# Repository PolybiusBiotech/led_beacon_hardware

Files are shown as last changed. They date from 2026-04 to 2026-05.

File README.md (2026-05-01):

# LED Beacon 🚀
> Upgrading cheap LED beacons for professional DMX/Art-Net stage control.

Hardware Render <!-- Tip: Export a nice 3D render from KiCAD -->

## 🚀 Manufacturing Status
- [ ] **Design:** Completed
- [ ] **Prototyping:** In Progress
- [ ] **Production:** Pending

## 📋 Quick Specs
- **MCU:** ESP32-C3-WROOM-02
- **Power:** +12V ±30% @ 2A
- **Connectivity:** DMX512 via 5 pin XLRs and WiFi

## 📂 Project Structure
- `/hardware`: KiCAD project files (Version 9.0.7).
- `/firmware`: PlatformIO project (Arduino/ESP-IDF framework).
- `/mechanical`: 3D-printable housing (.STEP).
- `/docs`: Specification, schematics and design calculations.
<!-- test: for test scripts -->

## 🛠 Setup & Development

### Hardware
- **Library Dependencies:** All footprints/symbols are [local to the repo / use standard KiCAD libs].
- **CI/CD:** Schematics are automatically exported to `/docs` on every push.

### Firmware
1. Open the `/firmware` folder in **VS Code**.
2. Ensure the **PlatformIO** extension is installed.
3. Connect your hardware via USB C port and click **Upload**.

## User Guide

1. Apply power via DC connector, 12V ±30% from a 3A capable supply.
2. Attach to DMX chain with 2x XLR 5pin cables
   * If at the end of the bus use a terminator plug
3. Select a DMX address with the DIP switch
   * This light consumes 20 slots so avoid address above 492.
   * Ensure that this light is >20 slots away from the next lights.
4. Disable the WiFi AP with the DIP switch unless needed for diagnostics
5. Use your DMX controller to send packets on the DMX chain.
   * Slots 1 to 10 control the brightness per channel
     * `0x00` is off
     * `0xFF` is on
   * Slots 11 to 20 control the strobe effect per channel
     * `0x00` is fully on
     * `0x01` strobes at 0.2Hz
     * `0xFF` strobes at 20Hz
6. Enjoy!

---
*Commissioned for Null Sector for EMF Camp 2026.*

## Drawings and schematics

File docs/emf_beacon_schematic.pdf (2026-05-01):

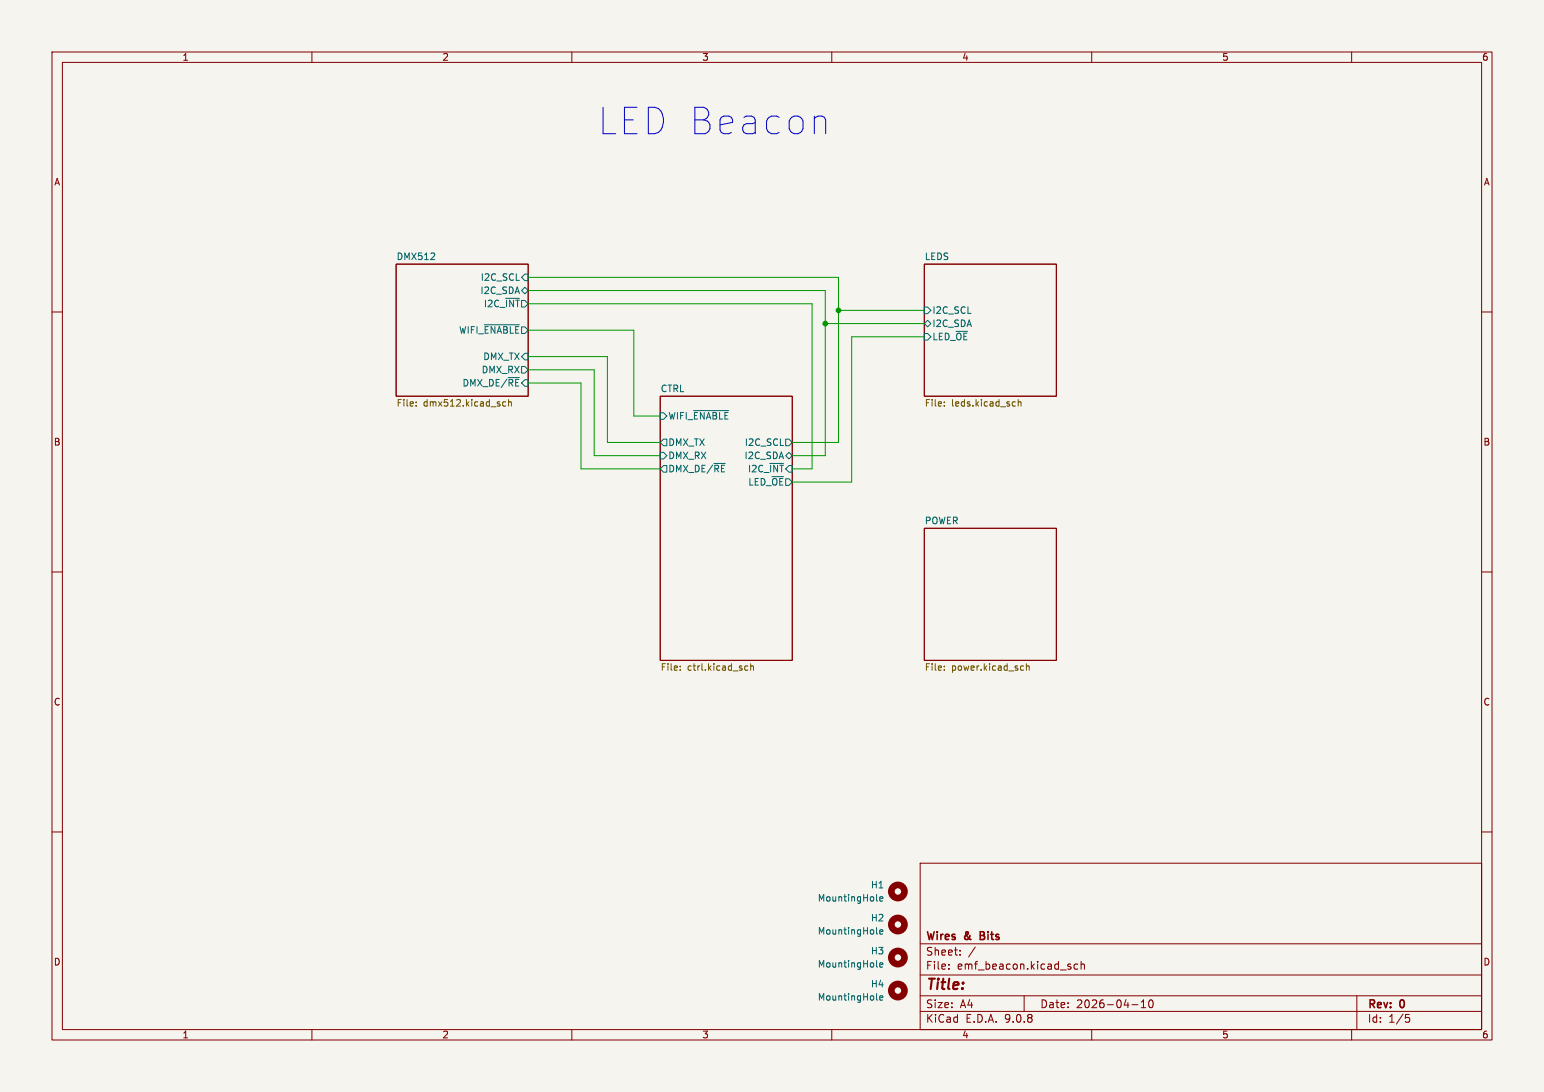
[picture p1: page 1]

WIFI_~{ENABLE} CTRL File: ctrl.kicad_sch DMX_DE/~{RE} DMX_RX DMX_TX

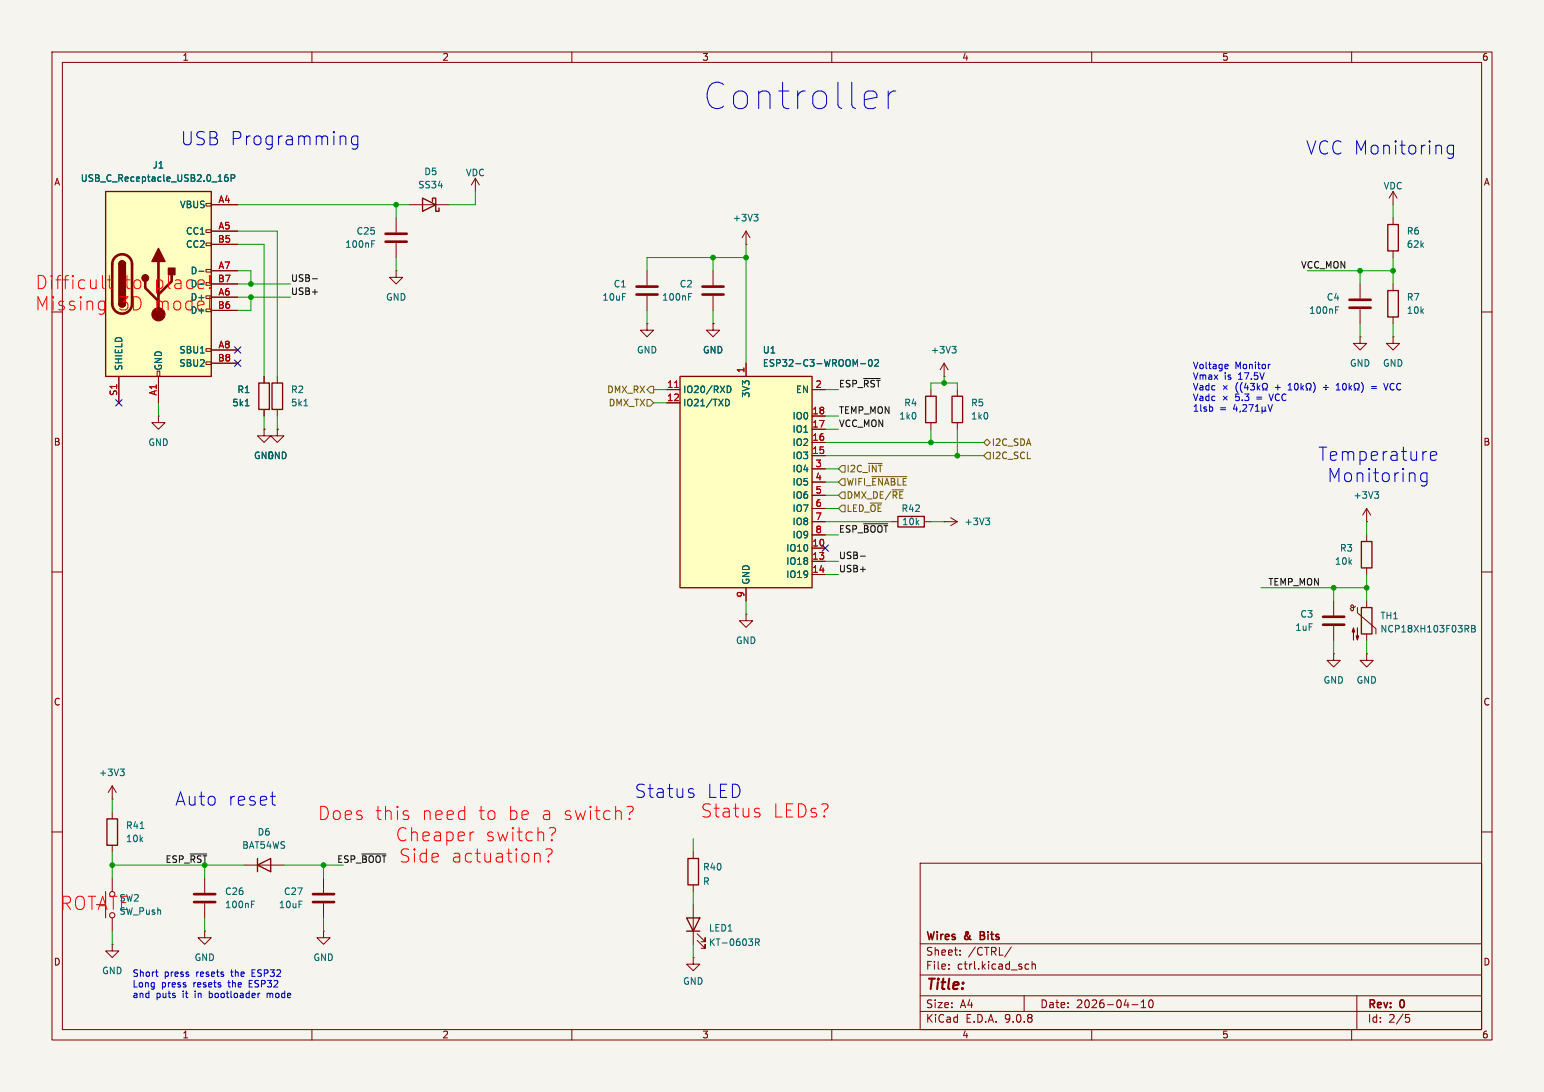
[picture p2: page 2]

Voltage Monitor Vmax is 17.5V

Vadc þÿ×þÿ((43k©+ þÿ10k©) þÿ÷þÿ10k©) = VCC
Vadc þÿ×5.3 = VCC
1lsb = þÿ4,271¼V

ESP_~{BOOT} USB+ Does this need to be a switch?

Short press resets the ESP32
Long press resets the ESP32

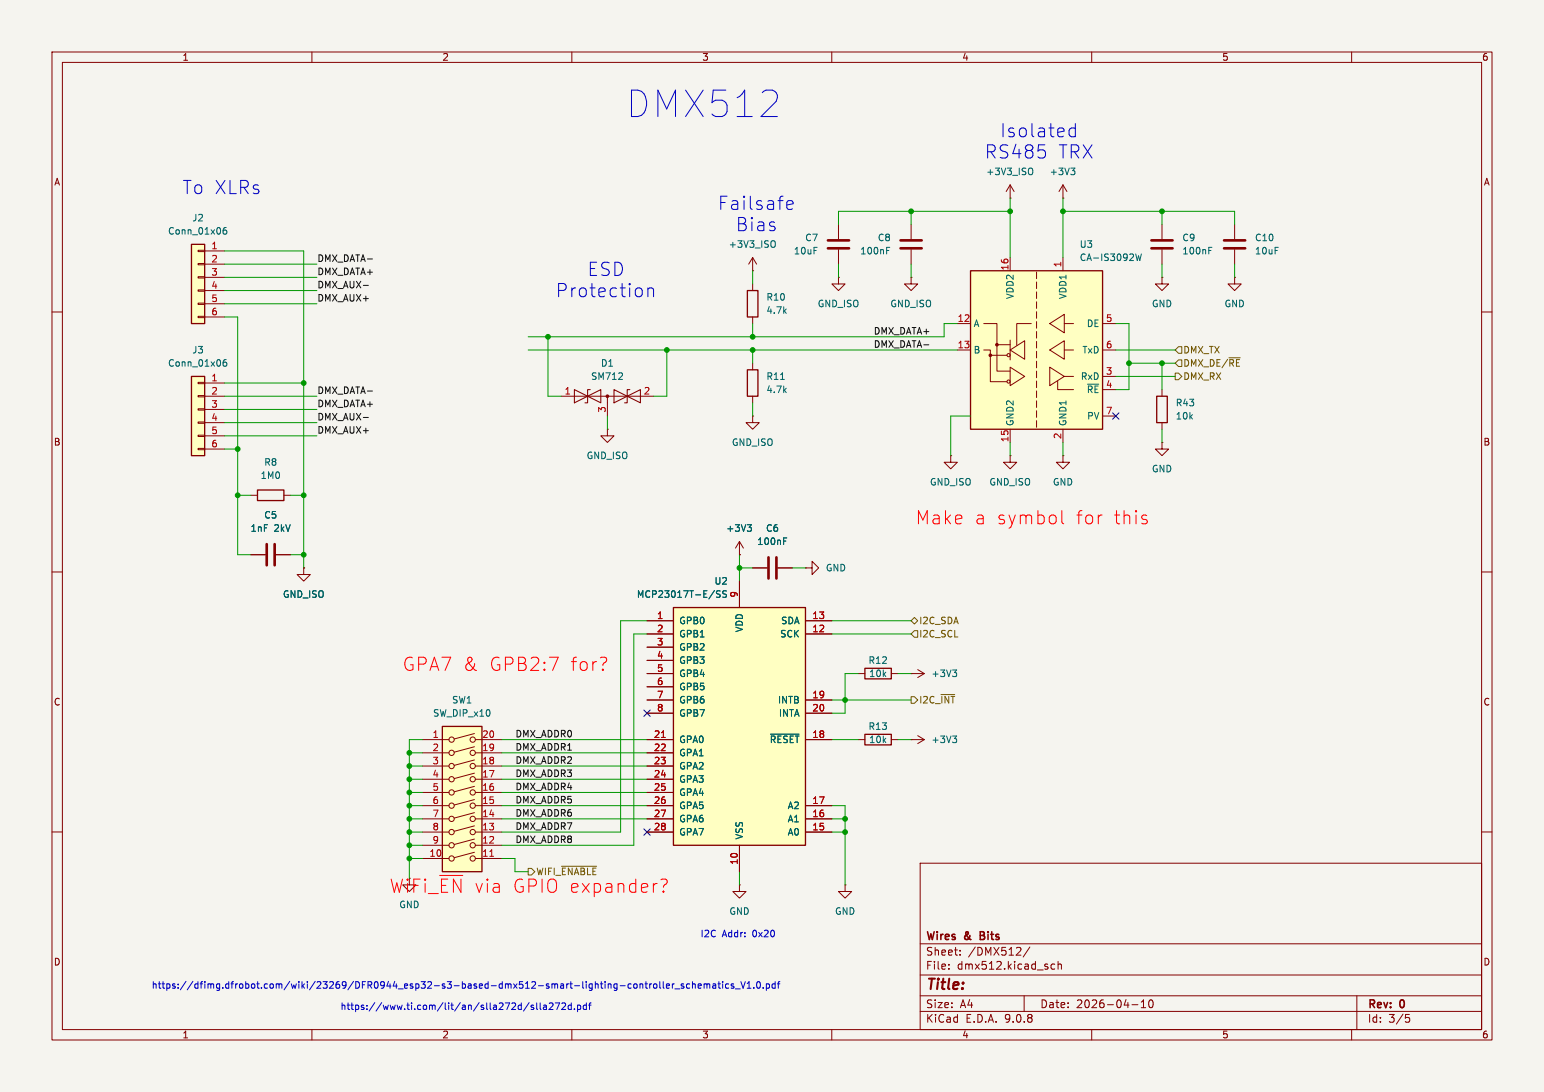
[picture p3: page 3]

9 VSS 10 GPB0 1 GPB1 2 GPB2 3 GPB3 4 GPB4 5 GPB5 6 GPB6 7 GPB7 8 GPA0 21 GPA1 22 GPA2 23 GPA3 24 GPA4 25 GPA5 26 GPA6 27 GPA7 28 U2 MCP23017T-E/SS GND GND GND GND_ISO

https://dfimg.dfrobot.com/wiki/23269/DFR0944_esp32-s3-based-dmx512-smart-lighting-controller_schematics_V1.0.pdf

https://www.ti.com/lit/an/slla272d/slla272d.pdf

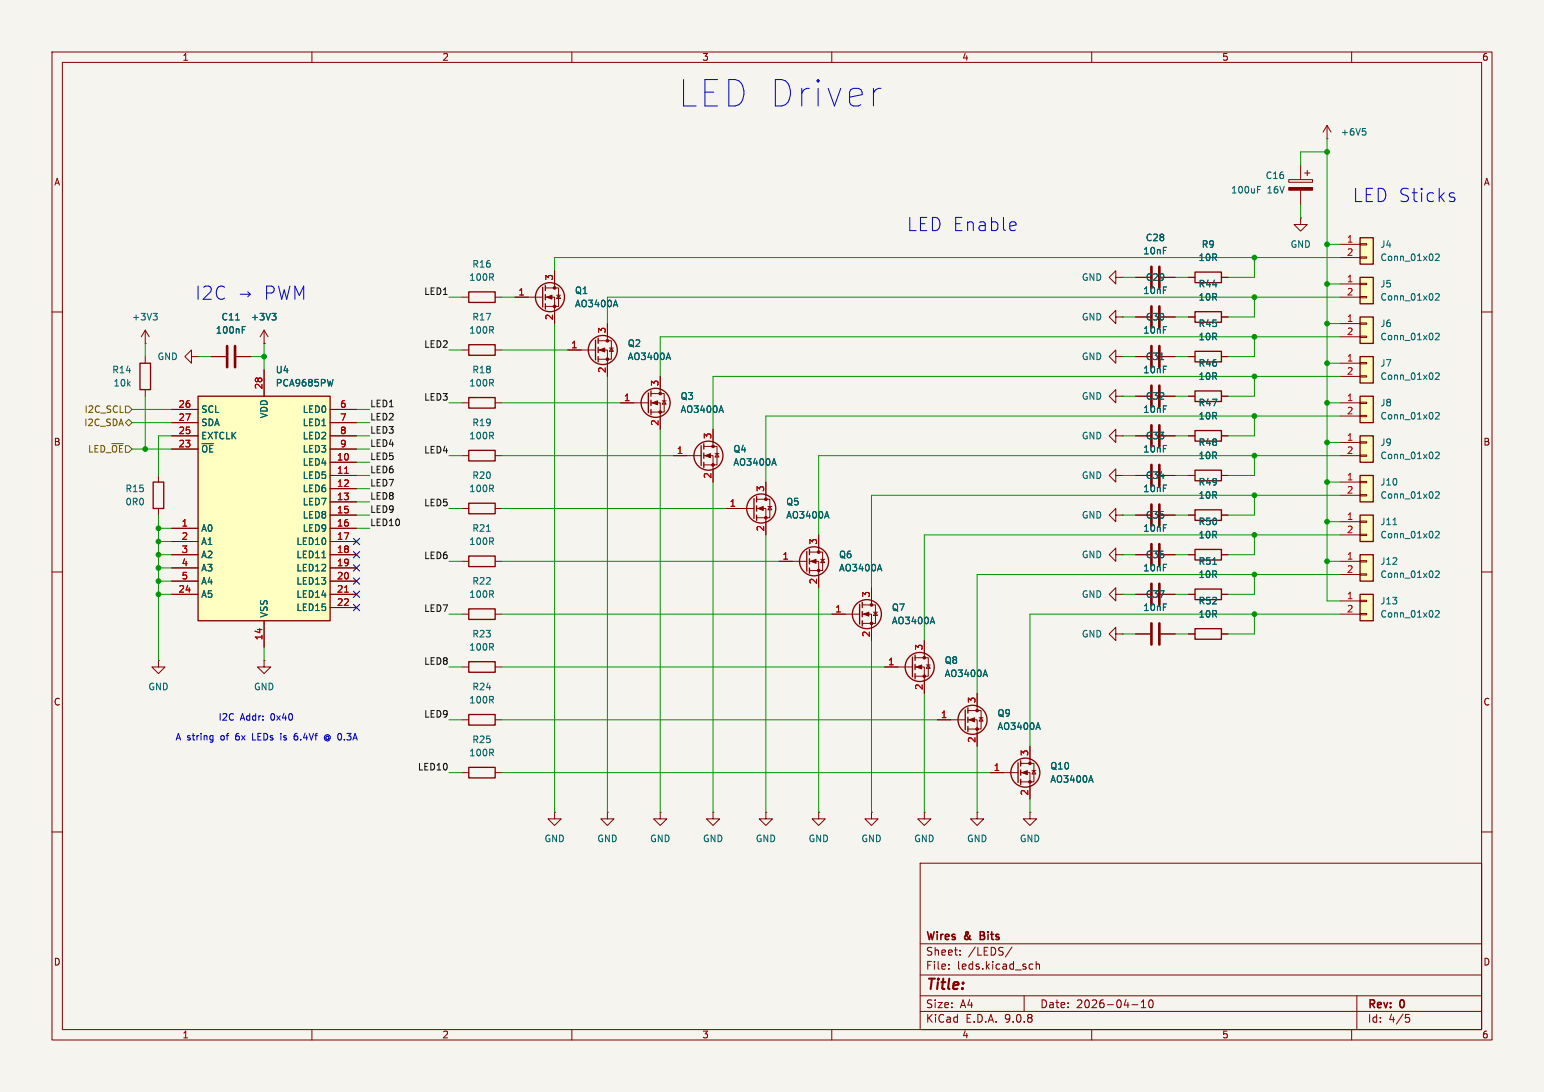
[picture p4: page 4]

3 2 Q10 AO3400A GND GND GND GND GND GND GND

A string of 6x LEDs is 6.4Vf @ 0.3A

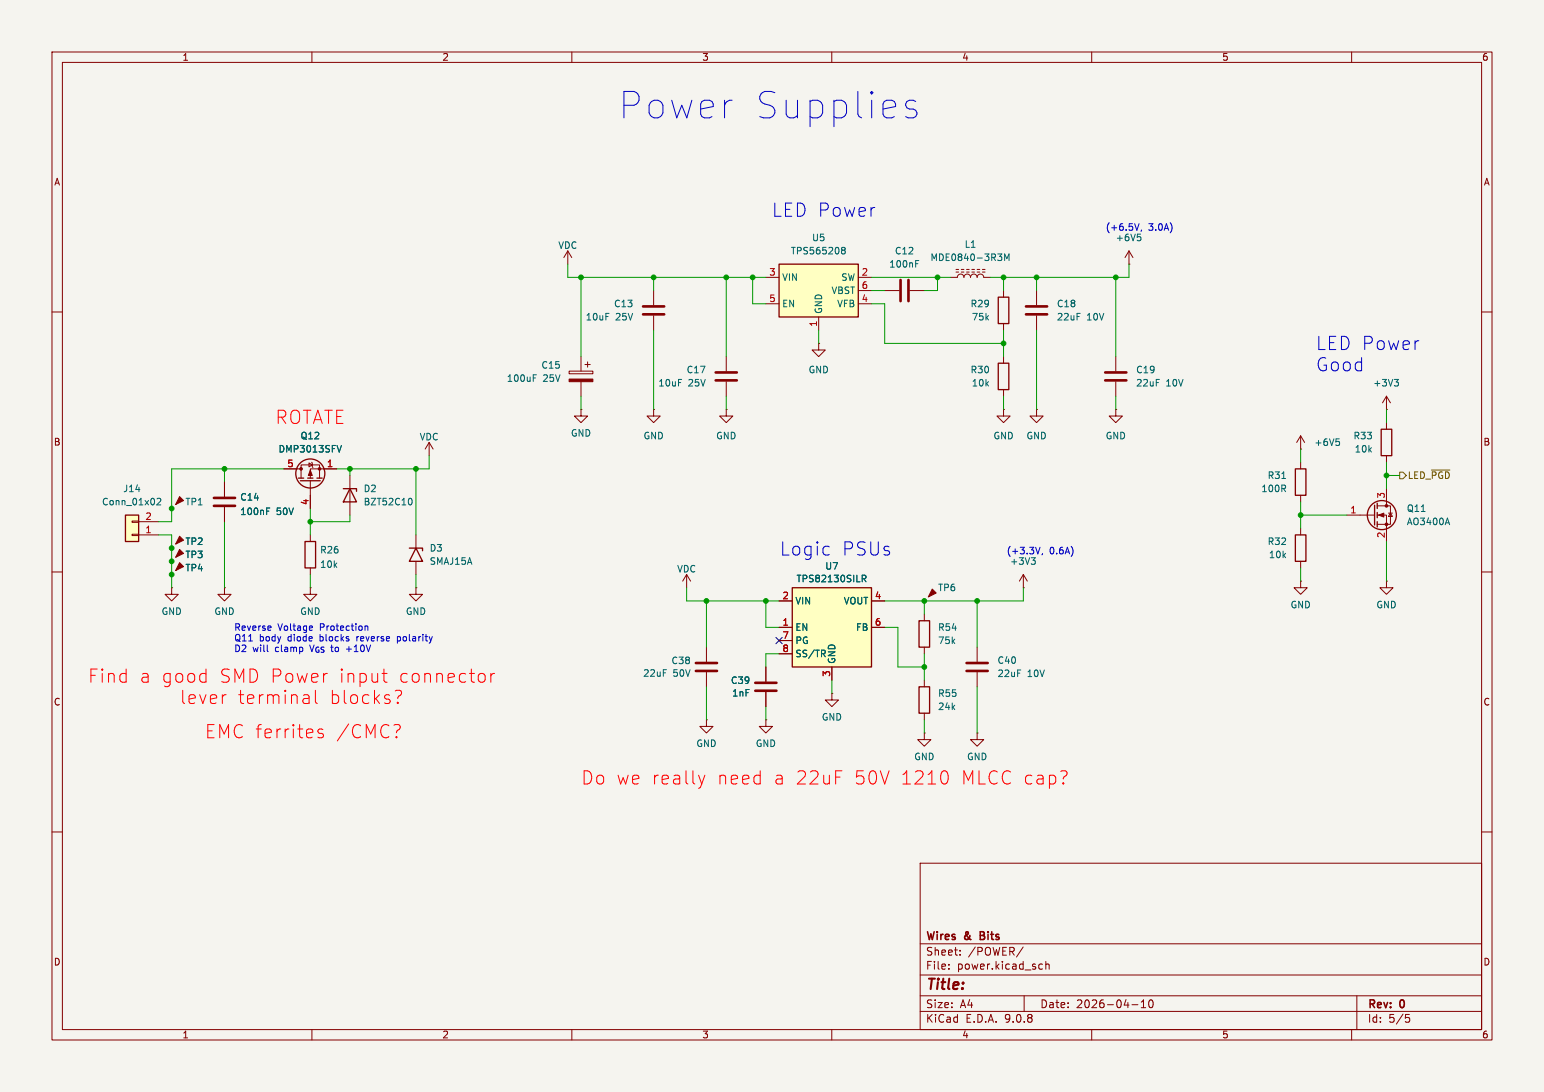
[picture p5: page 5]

Find a good SMD Power input connector

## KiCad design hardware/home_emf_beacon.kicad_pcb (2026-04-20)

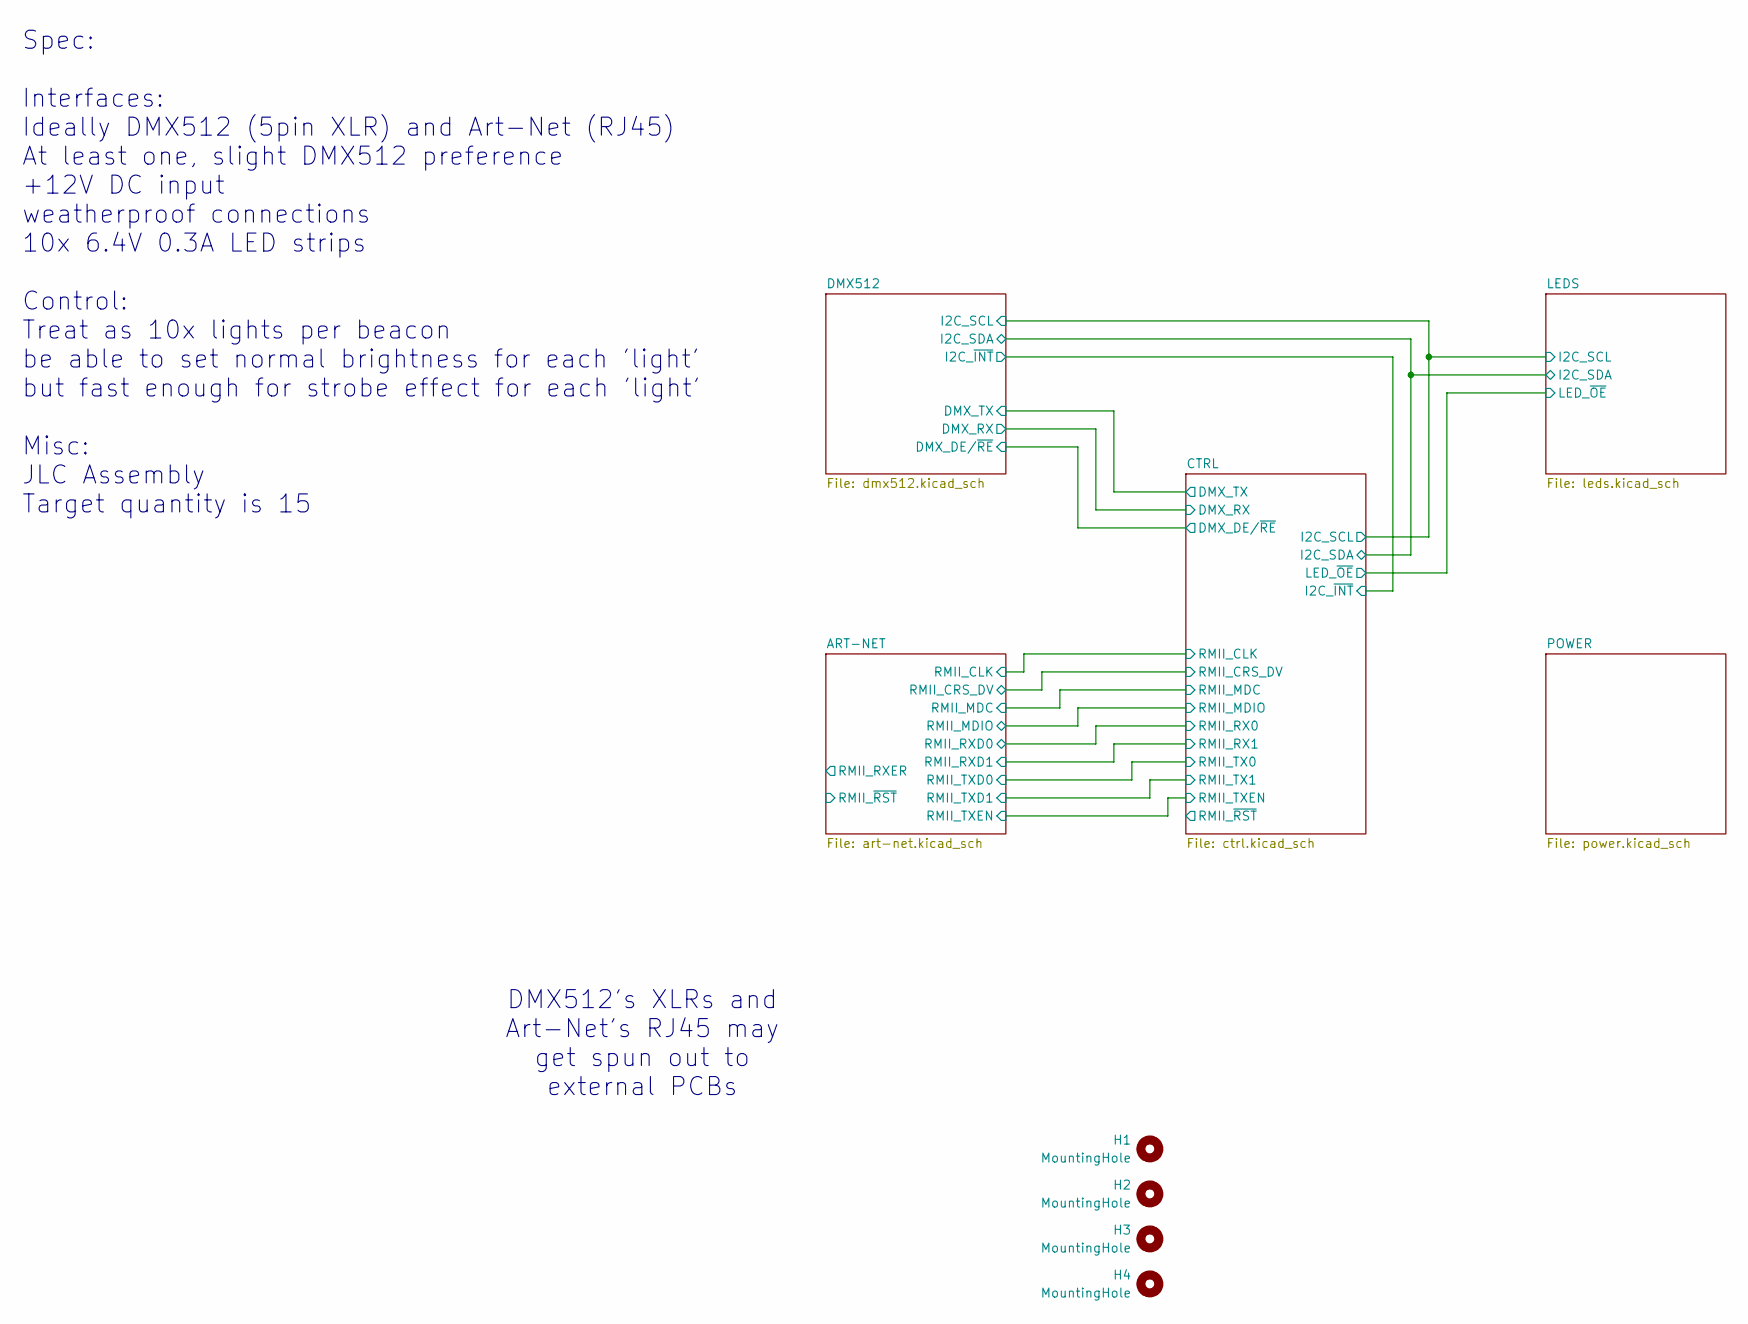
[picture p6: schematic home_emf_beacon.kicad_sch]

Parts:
H1, H2, H3, H4: MountingHole; MountingHole_4.3mm_M4

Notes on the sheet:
Spec: Interfaces: Ideally DMX512 (5pin XLR) and Art-Net (RJ45) At least one, slight DMX512 preference +12V DC input weatherproof connections 10x 6.4V 0.3A LED strips Control: Treat as 10x lights per beacon be able to set normal brightness for each 'light' but fast enough for strobe effect for each 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
DMX512's XLRs and Art-Net's RJ45 may get spun out to external PCBs

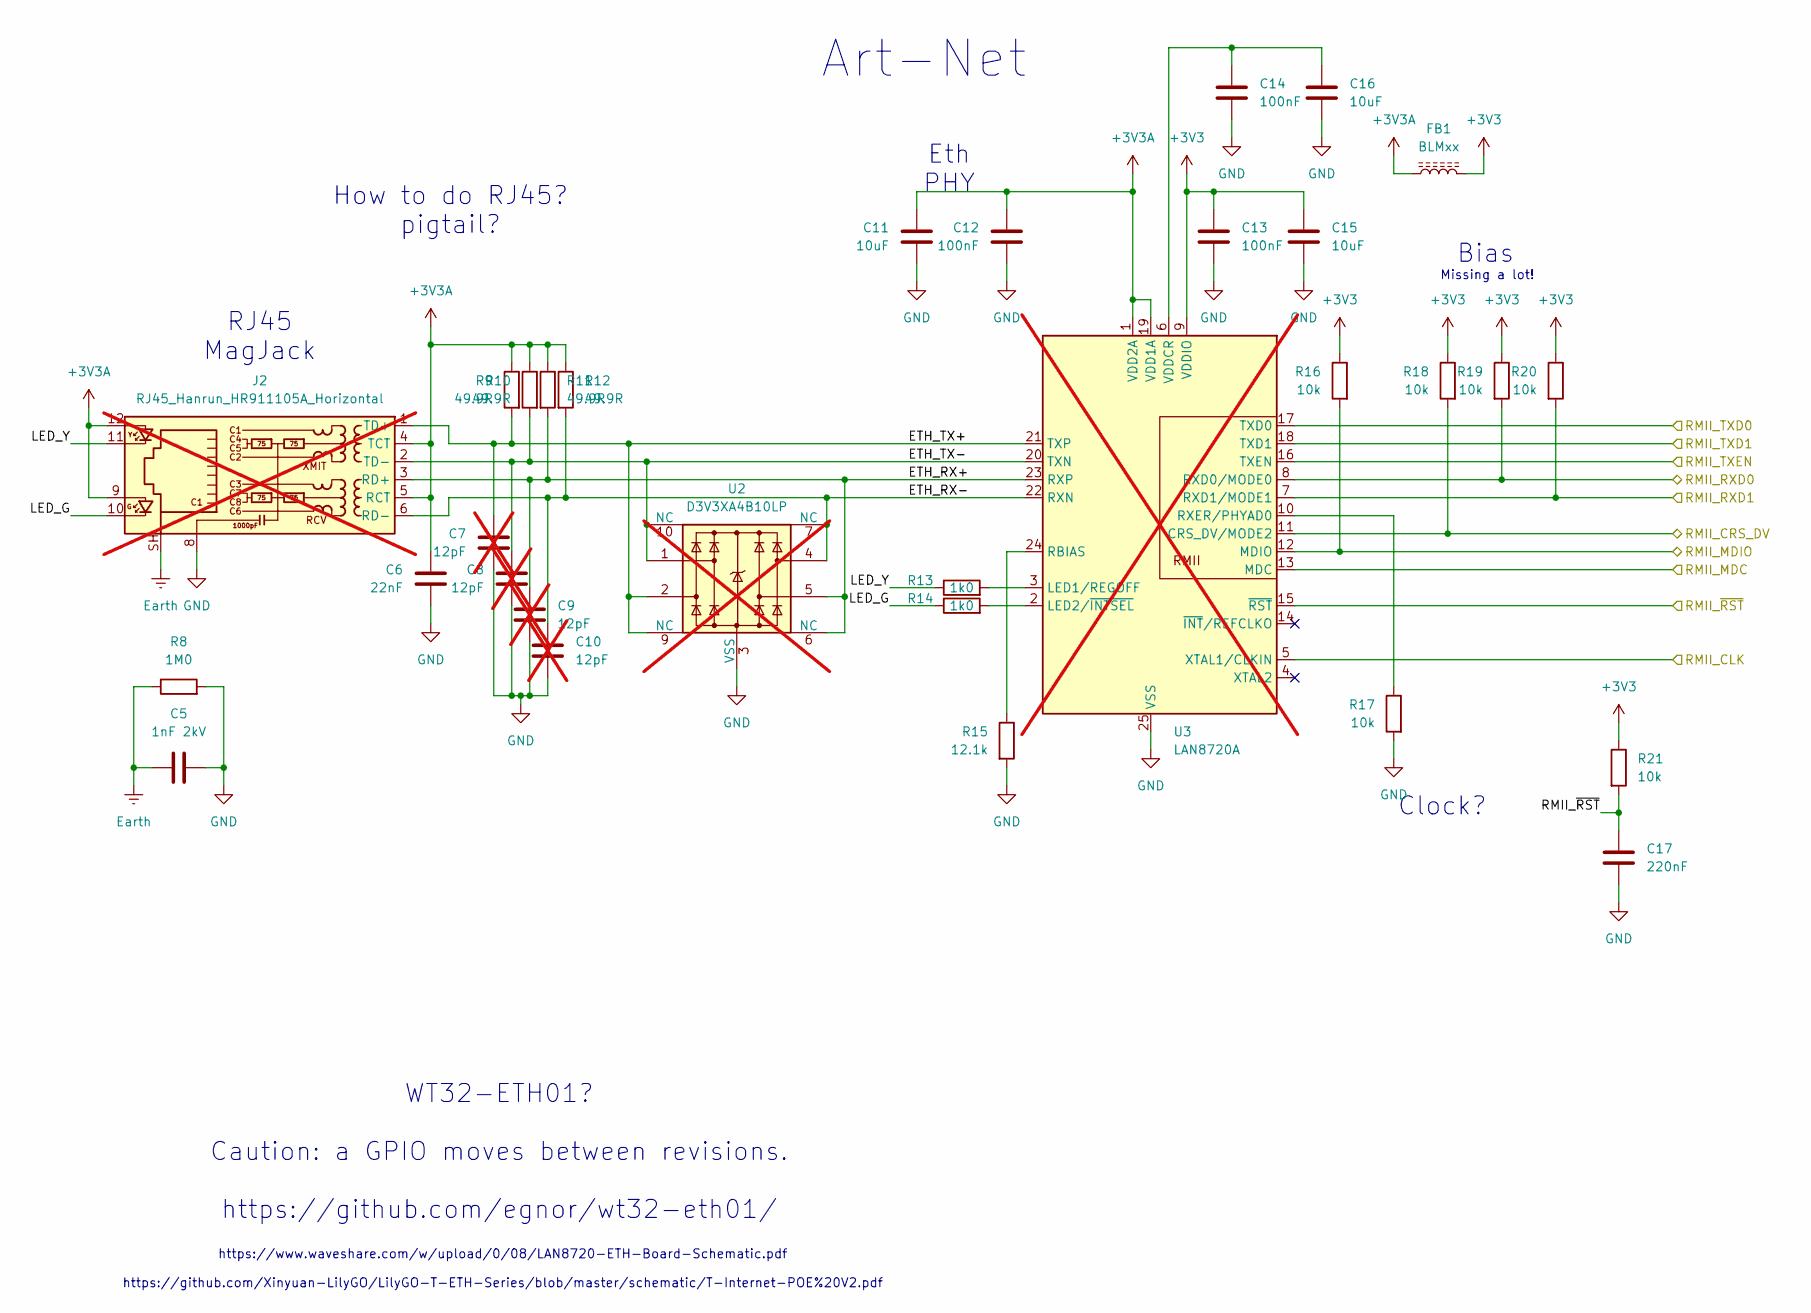
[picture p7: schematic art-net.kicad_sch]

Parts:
C5: 1nF 2kV; C_1808_4520Metric
C6: 22nF; C_0603_1608Metric
C7, C8, C9, C10: 12pF; C_0603_1608Metric; not fitted
C11, C15, C16: 10uF; C_0805_2012Metric
C12, C13, C14: 100nF; C_0603_1608Metric
C17: 220nF; C_0603_1608Metric
FB1: BLMxx; L_0603_1608Metric
J2: RJ45_Hanrun_HR911105A_Horizontal; LCSC C12074; not fitted
R8: 1M0; R_1206_3216Metric
R9, R10, R11, R12: 49.9R; R_0603_1608Metric
R13, R14: 1k0; R_0603_1608Metric
R15: 12.1k; R_0603_1608Metric
R16, R17, R18, R19, R20, R21: 10k; R_0603_1608Metric
U2: D3V3XA4B10LP; Diodes_UDFN-10_1x2.5mm_P0.5mm; not fitted
U3: LAN8720A; VQFN-24-1EP_4x4mm_P0.5mm_EP2.5x2.5mm_ThermalVias; not fitted

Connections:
+3V3: C13.2, C15.2, FB1.2, R16.1, R18.1, R19.1, R20.1, R21.1, U3.9 (VDDIO); also elsewhere on the board
+3V3A: C6.1, C11.2, C12.2, FB1.1, J2.4 (TCT), J2.5 (RCT), J2.9, J2.12, R9.1, R10.1, R11.1, R12.1, U3.1 (VDD2A), U3.19 (VDD1A)
/ART-NET/ETH_RX+: C9.1, J2.3 (RD+), R11.2, U2.5, U2.6 (NC), U3.23 (RXP)
/ART-NET/ETH_RX-: C10.1, J2.6 (RD-), R12.2, U2.4, U2.7 (NC), U3.22 (RXN)
/ART-NET/ETH_TX+: C7.1, J2.1 (TD+), R9.2, U2.2, U2.9 (NC), U3.21 (TXP)
/ART-NET/ETH_TX-: C8.1, J2.2 (TD-), R10.2, U2.1, U2.10 (NC), U3.20 (TXN)
/ART-NET/LED_G: J2.10, R14.1
/ART-NET/LED_Y: J2.11, R13.1
/ART-NET/RMII_~RST: C17.1, R21.2, U3.15 (~RST)
/CTRL/RMII_CLK: U3.5 (XTAL1/CLKIN); also elsewhere on the board
/CTRL/RMII_CRS_DV: R18.2, U3.11 (CRS_DV/MODE2); also elsewhere on the board
/CTRL/RMII_MDC: U3.13 (MDC); also elsewhere on the board
/CTRL/RMII_MDIO: R16.2, U3.12 (MDIO); also elsewhere on the board
/CTRL/RMII_RX0: R19.2, U3.8 (RXD0/MODE0); also elsewhere on the board
/CTRL/RMII_RX1: R20.2, U3.7 (RXD1/MODE1); also elsewhere on the board
/CTRL/RMII_TX0: U3.17 (TXD0); also elsewhere on the board
/CTRL/RMII_TX1: U3.18 (TXD1); also elsewhere on the board
/CTRL/RMII_TXEN: U3.16 (TXEN); also elsewhere on the board
Earth: C5.1, J2.SH, R8.1
GND: C5.2, C6.2, C7.2, C8.2, C9.2, C10.2, C11.1, C12.1, C13.1, C14.1, C15.1, C16.1, C17.2, J2.8, R8.2, R15.2, R17.2, U2.3 (VSS), U2.8 (VSS), U3.25 (VSS); also elsewhere on the board
unnamed: R13.2, U3.3 (LED1/REGOFF)
unnamed: R14.2, U3.2 (LED2/~INTSEL)
unnamed: R15.1, U3.24 (RBIAS)
unnamed: R17.1, U3.10 (RXER/PHYAD0)
unnamed: C14.2, C16.2, U3.6 (VDDCR)

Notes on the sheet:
How to do RJ45? pigtail?
Bias
WT32-ETH01? Caution: a GPIO moves between revisions. https://github.com/egnor/wt32-eth01/
https://www.waveshare.com/w/upload/0/08/LAN8720-ETH-Board-Schematic.pdf https://github.com/Xinyuan-LilyGO/LilyGO-T-ETH-Series/blob/master/schematic/T-Internet-POE%20V2.pdf
RJ45 MagJack
Art-Net
Eth PHY
Missing a lot!
Clock?

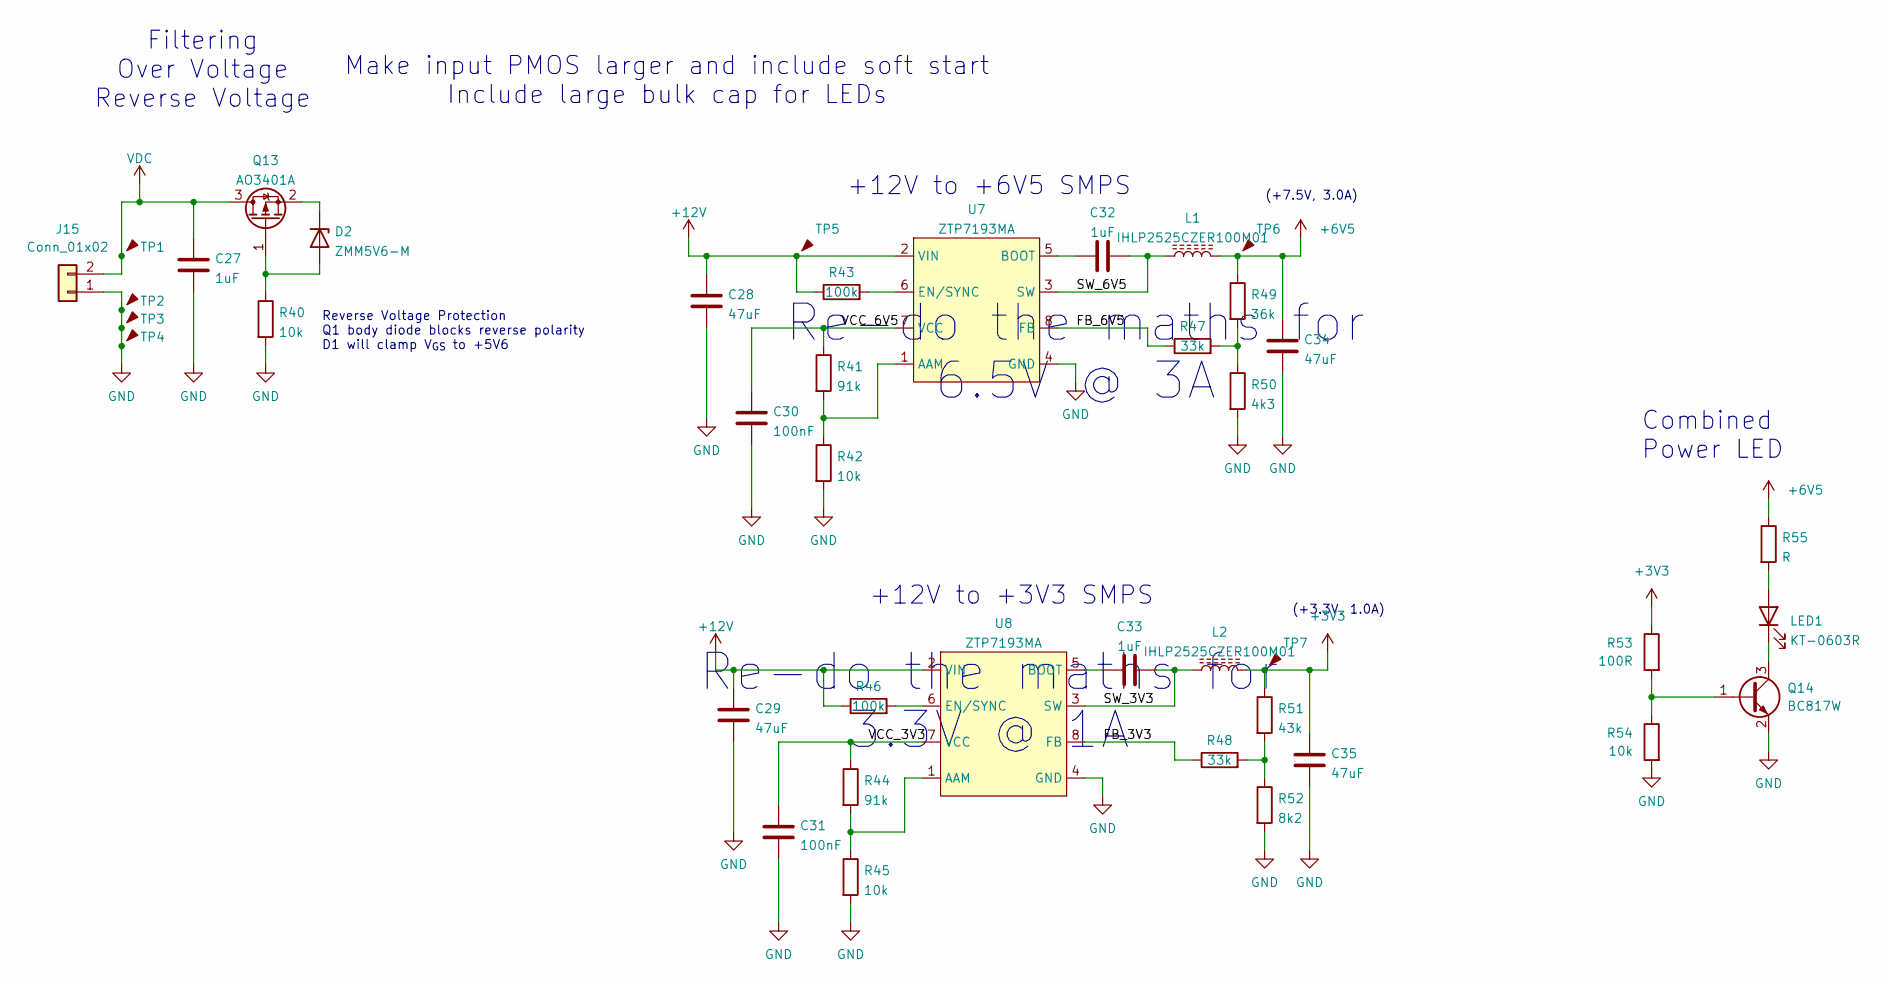
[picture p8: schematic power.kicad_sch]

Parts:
C27, C32, C33: 1uF; C_0603_1608Metric; Voltage 50V; LCSC C15849
C28, C29, C34, C35: 47uF; C_1210_3225Metric; Voltage 25V; LCSC C77101
C30, C31: 100nF; C_0603_1608Metric; Voltage 50V; LCSC C14663
D2: ZMM5V6-M; D_MiniMELF; LCSC C8062
J15: Conn_01x02; PhoenixContact_MSTBVA_2,5_2-G-5,08_1x02_P5.08mm_Vertical
L1, L2: IHLP2525CZER100M01; L_Vishay_IHLP-2525; LCSC C540965
LED1: KT-0603R; LED_0603_1608Metric; LCSC C2286
Q13: AO3401A; SOT-23; LCSC C15127
Q14: BC817W; SOT-323_SC-70
R40, R42, R45: 10k; R_0603_1608Metric; LCSC C25804
R41, R44: 91k; R_0603_1608Metric; LCSC C23265
R43, R46: 100k; R_0603_1608Metric; LCSC C25803
R47, R48: 33k; R_0603_1608Metric; LCSC C4216
R49: 36k; R_0603_1608Metric; LCSC C23147
R50: 4k3; R_0603_1608Metric; LCSC C23159
R51: 43k; R_0603_1608Metric; LCSC C23172
R52: 8k2; R_0603_1608Metric; LCSC C25981
R53: 100R; R_0603_1608Metric
R54: 10k; R_0603_1608Metric
R55: R; R_0603_1608Metric
TP1, TP2, TP3, TP4, TP5, TP6, TP7: TestPoint; TestPoint_Pad_D1.5mm
U7, U8: ZTP7193MA; SOT-23-8; LCSC C481284

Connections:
+3V3: C35.1, L2.2, R51.1, R53.1, TP7.1; also elsewhere on the board
+6V5: C34.1, L1.2, R49.1, R55.1, TP6.1; also elsewhere on the board
+12V: C28.1, C29.1, R43.1, R46.1, TP5.1, U7.2 (VIN), U8.2 (VIN)
/POWER/FB_3V3: R48.1, U8.8 (FB)
/POWER/FB_6V5: R47.1, U7.8 (FB)
/POWER/SW_3V3: C33.2, L2.1, U8.3 (SW)
/POWER/SW_6V5: C32.2, L1.1, U7.3 (SW)
/POWER/VCC_3V3: C31.2, R44.1, U8.7 (VCC)
/POWER/VCC_6V5: C30.2, R41.1, U7.7 (VCC)
GND: C27.2, C28.2, C29.2, C30.1, C31.1, C34.2, C35.2, J15.1, Q14.2 (E), R40.2, R42.2, R45.2, R50.2, R52.2, R54.2, TP2.1, TP3.1, TP4.1, U7.4 (GND), U8.4 (GND); also elsewhere on the board
unnamed: D2.2 (A), Q13.1 (G), R40.1
unnamed: D2.1 (K), Q13.2 (S)
unnamed: LED1.2 (A), R55.2
unnamed: LED1.1 (K), Q14.3 (C)
unnamed: Q14.1 (B), R53.2, R54.1
unnamed: R47.2, R49.2, R50.1
unnamed: R48.2, R51.2, R52.1
unnamed: R41.2, R42.1, U7.1 (AAM)
unnamed: C32.1, U7.5 (BOOT)
unnamed: R43.2, U7.6 (EN/SYNC)
unnamed: R44.2, R45.1, U8.1 (AAM)
unnamed: C33.1, U8.5 (BOOT)
unnamed: R46.2, U8.6 (EN/SYNC)
VDC: C27.1, J15.2, Q13.3 (D), TP1.1

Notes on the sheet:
Make input PMOS larger and include soft start Include large bulk cap for LEDs
(+7.5V, 3.0A)
Re-do the maths for 3.3V @ 1A
Re-do the maths for 6.5V @ 3A
Filtering Over Voltage Reverse Voltage
Combined Power LED
(+3.3V, 1.0A)
+12V to +3V3 SMPS
+12V to +6V5 SMPS
Reverse Voltage Protection Q1 body diode blocks reverse polarity D1 will clamp V_{GS} to +5V6

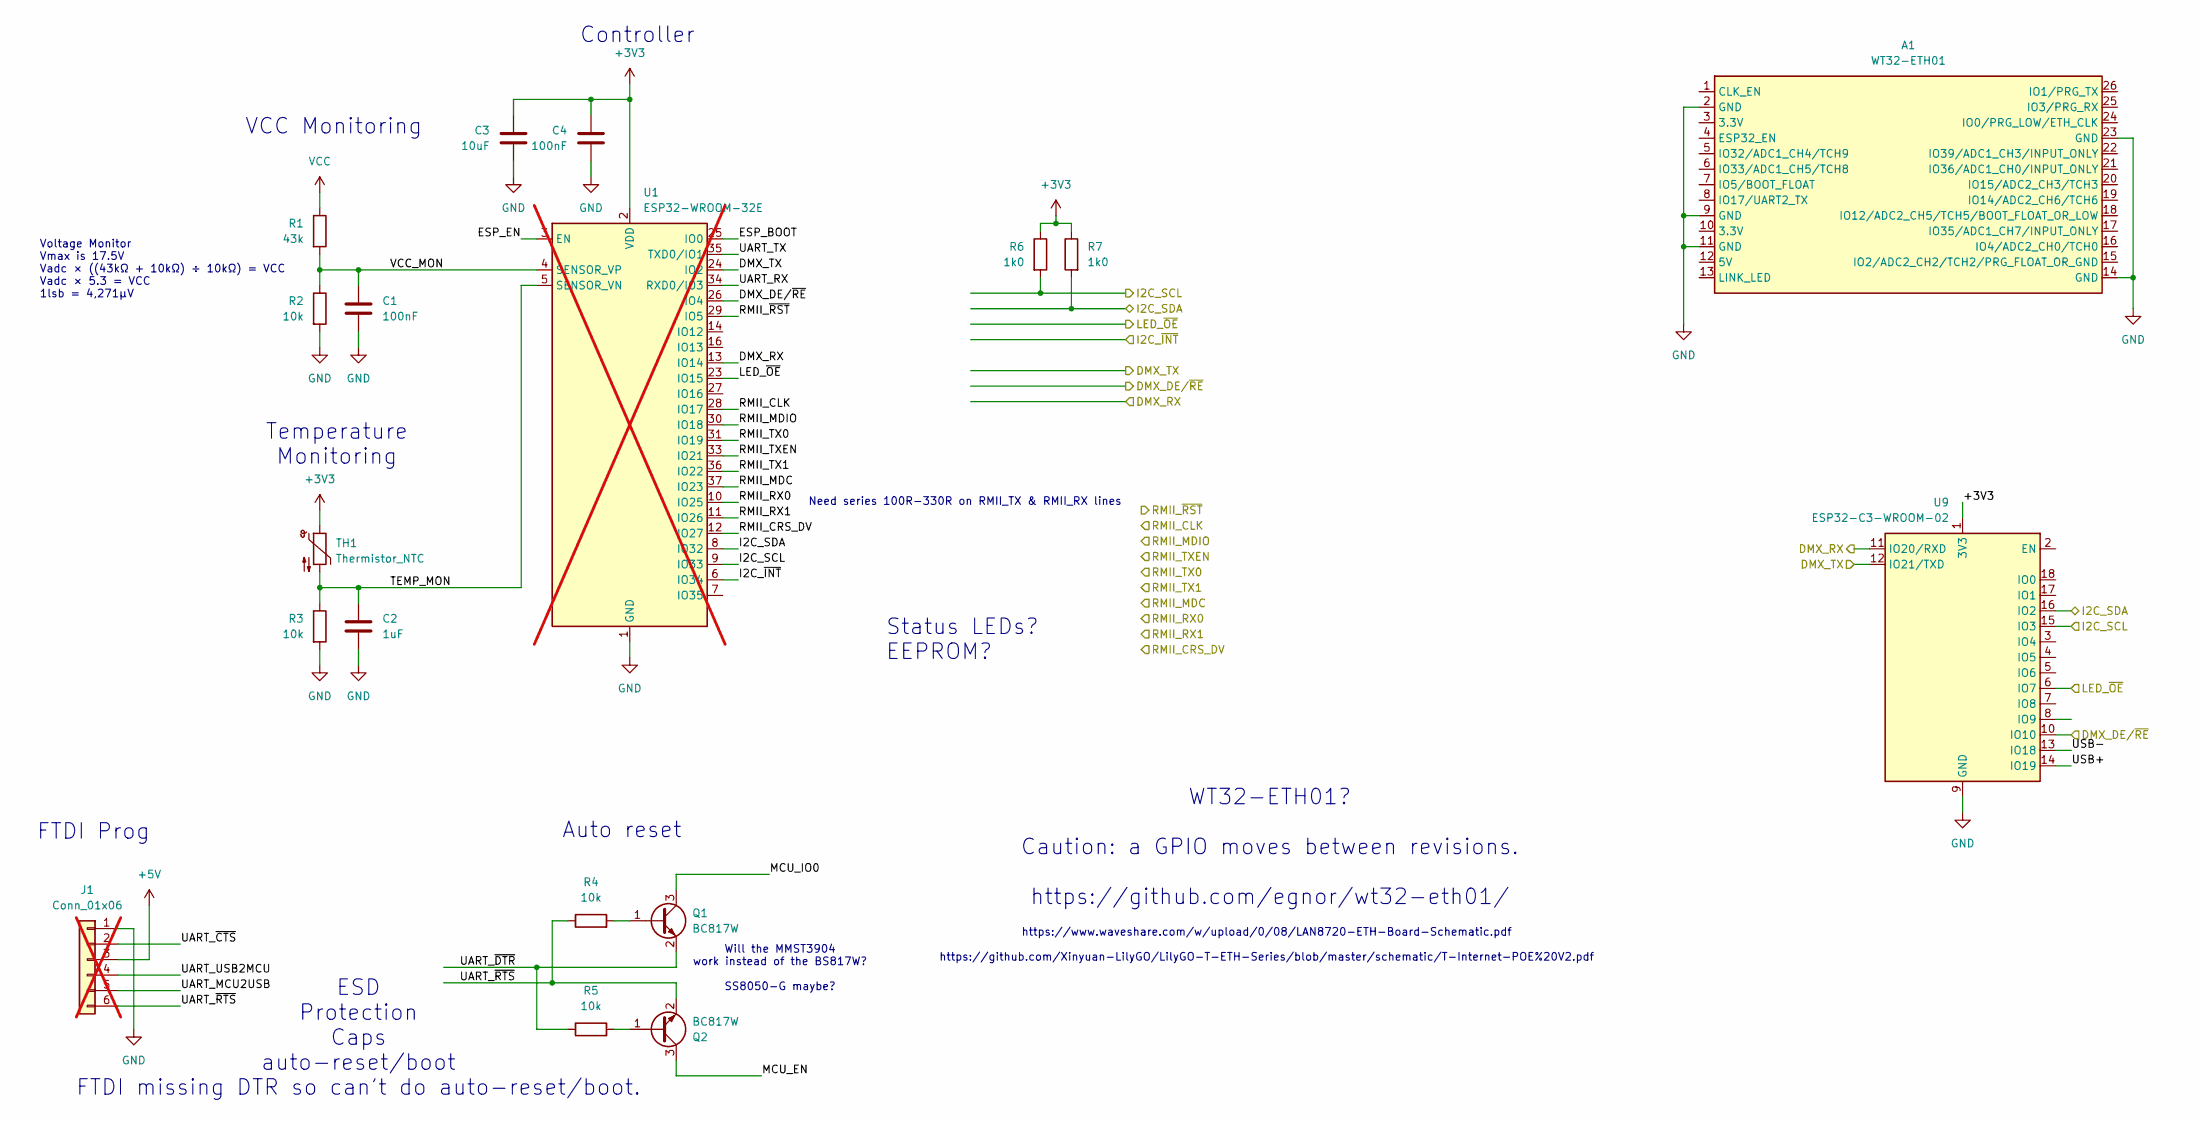
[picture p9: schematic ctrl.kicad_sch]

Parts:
A1: WT32-ETH01
C1, C4: 100nF; C_0603_1608Metric
C2: 1uF; C_0603_1608Metric
C3: 10uF; C_0805_2012Metric
J1: Conn_01x06; PinHeader_1x06_P2.54mm_Vertical; not fitted
Q1, Q2: BC817W; SOT-323_SC-70
R1: 43k; R_0603_1608Metric
R2, R3, R4, R5: 10k; R_0603_1608Metric
R6, R7: 1k0; R_0603_1608Metric
TH1: Thermistor_NTC; R_0603_1608Metric
U1: ESP32-WROOM-32E; ESP32-WROOM-32D; not fitted
U9: ESP32-C3-WROOM-02

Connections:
+3V3: C3.1, C4.1, R6.1, R7.1, TH1.1, U1.2 (VDD), U9.1 (3V3); also elsewhere on the board
+5V: J1.3
/CTRL/DMX_DE/~RE: U1.26 (IO4), U9.10 (IO10); also elsewhere on the board
/CTRL/DMX_RX: U1.13 (IO14), U9.11 (IO20/RXD); also elsewhere on the board
/CTRL/DMX_TX: U1.24 (IO2), U9.12 (IO21/TXD); also elsewhere on the board
/CTRL/ESP_BOOT: U1.25 (IO0)
/CTRL/ESP_EN: U1.3 (EN)
/CTRL/I2C_SCL: R6.2, U1.9 (IO33), U9.15 (IO3); also elsewhere on the board
/CTRL/I2C_SDA: R7.2, U1.8 (IO32), U9.16 (IO2); also elsewhere on the board
/CTRL/I2C_~INT: U1.6 (IO34); also elsewhere on the board
/CTRL/LED_~OE: U1.23 (IO15), U9.6 (IO7); also elsewhere on the board
/CTRL/MCU_EN: Q2.3 (C)
/CTRL/MCU_IO0: Q1.3 (C)
/CTRL/RMII_CLK: U1.28 (IO17); also elsewhere on the board
/CTRL/RMII_CRS_DV: U1.12 (IO27); also elsewhere on the board
/CTRL/RMII_MDC: U1.37 (IO23); also elsewhere on the board
/CTRL/RMII_MDIO: U1.30 (IO18); also elsewhere on the board
/CTRL/RMII_RX0: U1.10 (IO25); also elsewhere on the board
/CTRL/RMII_RX1: U1.11 (IO26); also elsewhere on the board
/CTRL/RMII_TX0: U1.31 (IO19); also elsewhere on the board
/CTRL/RMII_TX1: U1.36 (IO22); also elsewhere on the board
/CTRL/RMII_TXEN: U1.33 (IO21); also elsewhere on the board
/CTRL/RMII_~RST: U1.29 (IO5)
/CTRL/TEMP_MON: C2.1, R3.1, TH1.2, U1.5 (SENSOR_VN)
/CTRL/UART_MCU2USB: J1.5
/CTRL/UART_RX: U1.34 (RXD0/IO3)
/CTRL/UART_TX: U1.35 (TXD0/IO1)
/CTRL/UART_USB2MCU: J1.4
/CTRL/UART_~CTS: J1.2
/CTRL/UART_~DTR: Q1.2 (E), R5.1
/CTRL/UART_~RTS: J1.6, Q2.2 (E), R4.1
/CTRL/USB+: U9.14 (IO19)
/CTRL/USB-: U9.13 (IO18)
/CTRL/VCC_MON: C1.1, R1.2, R2.1, U1.4 (SENSOR_VP)
GND: A1.2 (GND), A1.9 (GND), A1.11 (GND), A1.14 (GND), A1.23 (GND), C1.2, C2.2, C3.2, C4.2, J1.1, R2.2, R3.2, U1.1 (GND), U1.15 (GND), U1.38 (GND), U1.39 (GND), U9.9 (GND), U9.19 (GND); also elsewhere on the board
unnamed: Q1.1 (B), R4.2
unnamed: Q2.1 (B), R5.2
VCC: R1.1

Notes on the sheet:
Auto reset
Status LEDs? EEPROM?
WT32-ETH01? Caution: a GPIO moves between revisions. https://github.com/egnor/wt32-eth01/
VCC Monitoring
Need series 100R-330R on RMII_TX & RMII_RX lines
Will the MMST3904 work instead of the BS817W? SS8050-G maybe?
https://www.waveshare.com/w/upload/0/08/LAN8720-ETH-Board-Schematic.pdf https://github.com/Xinyuan-LilyGO/LilyGO-T-ETH-Series/blob/master/schematic/T-Internet-POE%20V2.pdf
Temperature Monitoring
Controller
FTDI Prog
ESD Protection Caps auto-reset/boot FTDI missing DTR so can't do auto-reset/boot.
Voltage Monitor Vmax is 17.5V Vadc × ((43kΩ + 10kΩ) ÷ 10kΩ) = VCC Vadc × 5.3 = VCC 1lsb = 4,271μV

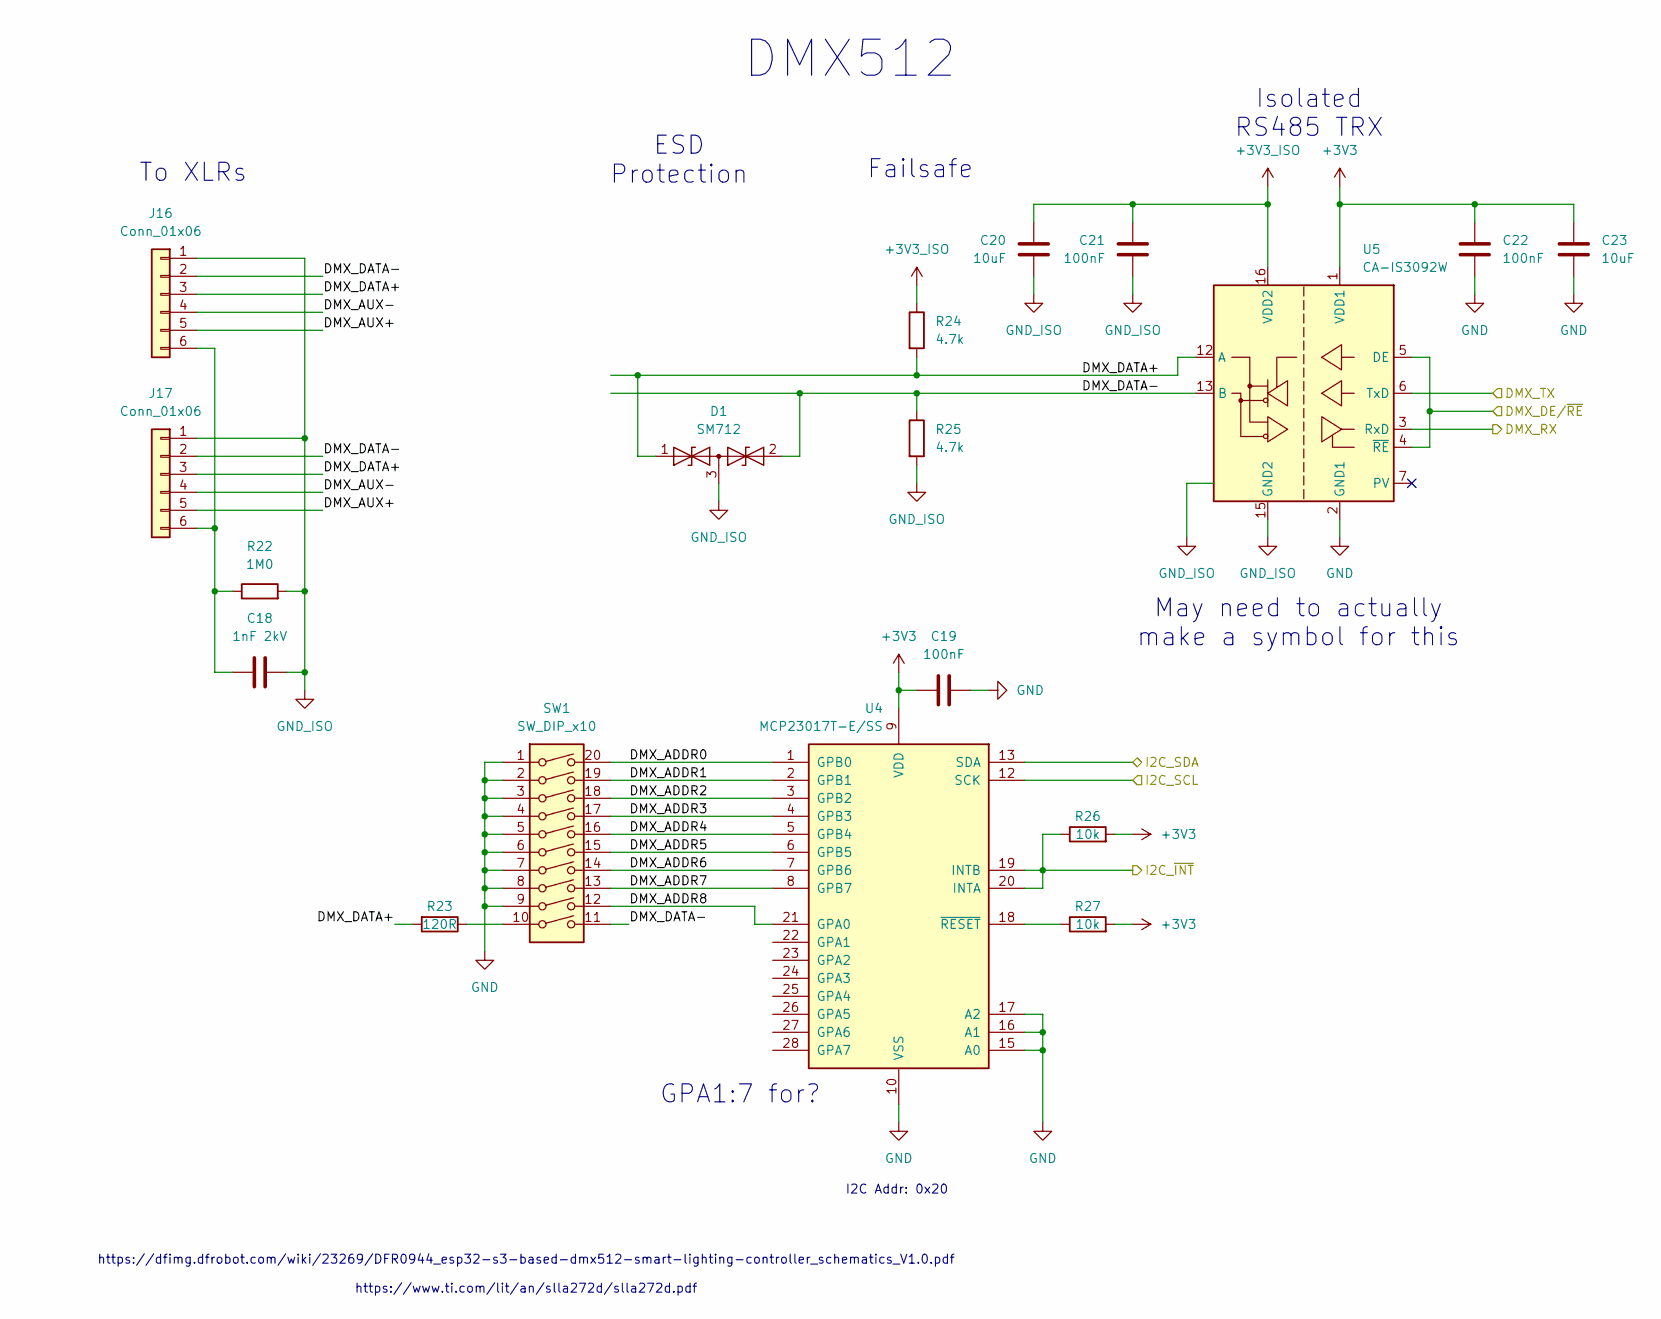
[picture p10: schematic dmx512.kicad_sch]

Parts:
C18: 1nF 2kV; C_1808_4520Metric
C19, C21, C22: 100nF; C_0603_1608Metric
C20, C23: 10uF; C_0805_2012Metric
D1: SM712; SOT-23; LCSC C7420375
J16, J17: Conn_01x06; JST_PH_B6B-PH-K_1x06_P2.00mm_Vertical
R22: 1M0; R_1206_3216Metric
R23: 120R; R_0805_2012Metric_Pad1.20x1.40mm_HandSolder
R24, R25: 4.7k; R_0603_1608Metric
R26, R27: 10k; R_0603_1608Metric
SW1: SW_DIP_x10; SW_DIP_SPSTx10_Slide_6.7x26.96mm_W7.62mm_P2.54mm_LowProfile; LCSC C509577
U4: MCP23017T-E/SS; SSOP-28_5.3x10.2mm_P0.65mm; LCSC C558584
U5: CA-IS3092W; SOIC-16W_7.5x10.3mm_P1.27mm; LCSC C2890051

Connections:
+3V3: C19.2, C22.1, C23.1, R26.2, R27.2, U4.9 (VDD), U5.1 (VDD1); also elsewhere on the board
+3V3_ISO: C20.1, C21.1, R24.1, U5.16 (VDD2)
/CTRL/DMX_DE/~RE: U5.4 (~RE), U5.5 (DE); also elsewhere on the board
/CTRL/DMX_RX: U5.3 (RxD); also elsewhere on the board
/CTRL/DMX_TX: U5.6 (TxD); also elsewhere on the board
/CTRL/I2C_SCL: U4.12 (SCK); also elsewhere on the board
/CTRL/I2C_SDA: U4.13 (SDA); also elsewhere on the board
/CTRL/I2C_~INT: R26.1, U4.19 (INTB), U4.20 (INTA); also elsewhere on the board
/DMX512/DMX_ADDR0: SW1.20, U4.1 (GPB0)
/DMX512/DMX_ADDR1: SW1.19, U4.2 (GPB1)
/DMX512/DMX_ADDR2: SW1.18, U4.3 (GPB2)
/DMX512/DMX_ADDR3: SW1.17, U4.4 (GPB3)
/DMX512/DMX_ADDR4: SW1.16, U4.5 (GPB4)
/DMX512/DMX_ADDR5: SW1.15, U4.6 (GPB5)
/DMX512/DMX_ADDR6: SW1.14, U4.7 (GPB6)
/DMX512/DMX_ADDR7: SW1.13, U4.8 (GPB7)
/DMX512/DMX_ADDR8: SW1.12, U4.21 (GPA0)
/DMX512/DMX_AUX+: J16.5, J17.5
/DMX512/DMX_AUX-: J16.4, J17.4
/DMX512/DMX_DATA+: D1.1 (A1), J16.3, J17.3, R23.2, R24.2, U5.12 (A)
/DMX512/DMX_DATA-: D1.2 (A2), J16.2, J17.2, R25.1, SW1.11, U5.13 (B)
GND: C19.1, C22.2, C23.2, SW1.1, SW1.2, SW1.3, SW1.4, SW1.5, SW1.6, SW1.7, SW1.8, SW1.9, U4.10 (VSS), U4.15 (A0), U4.16 (A1), U4.17 (A2), U5.2 (GND1), U5.8 (GND1); also elsewhere on the board
GND_ISO: C18.2, C20.2, C21.2, D1.3 (common), J16.1, J17.1, R22.2, R25.2, U5.9 (GND2), U5.15 (GND2)
unnamed: C18.1, J16.6, J17.6, R22.1
unnamed: R23.1, SW1.10
unnamed: R27.1, U4.18 (~RESET)

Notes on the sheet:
May need to actually make a symbol for this
I2C Addr: 0x20
Failsafe
DMX512
https://dfimg.dfrobot.com/wiki/23269/DFR0944_esp32-s3-based-dmx512-smart-lighting-controller_schematics_V1.0.pdf https://www.ti.com/lit/an/slla272d/slla272d.pdf
To XLRs
ESD Protection
GPA1:7 for?
Isolated RS485 TRX

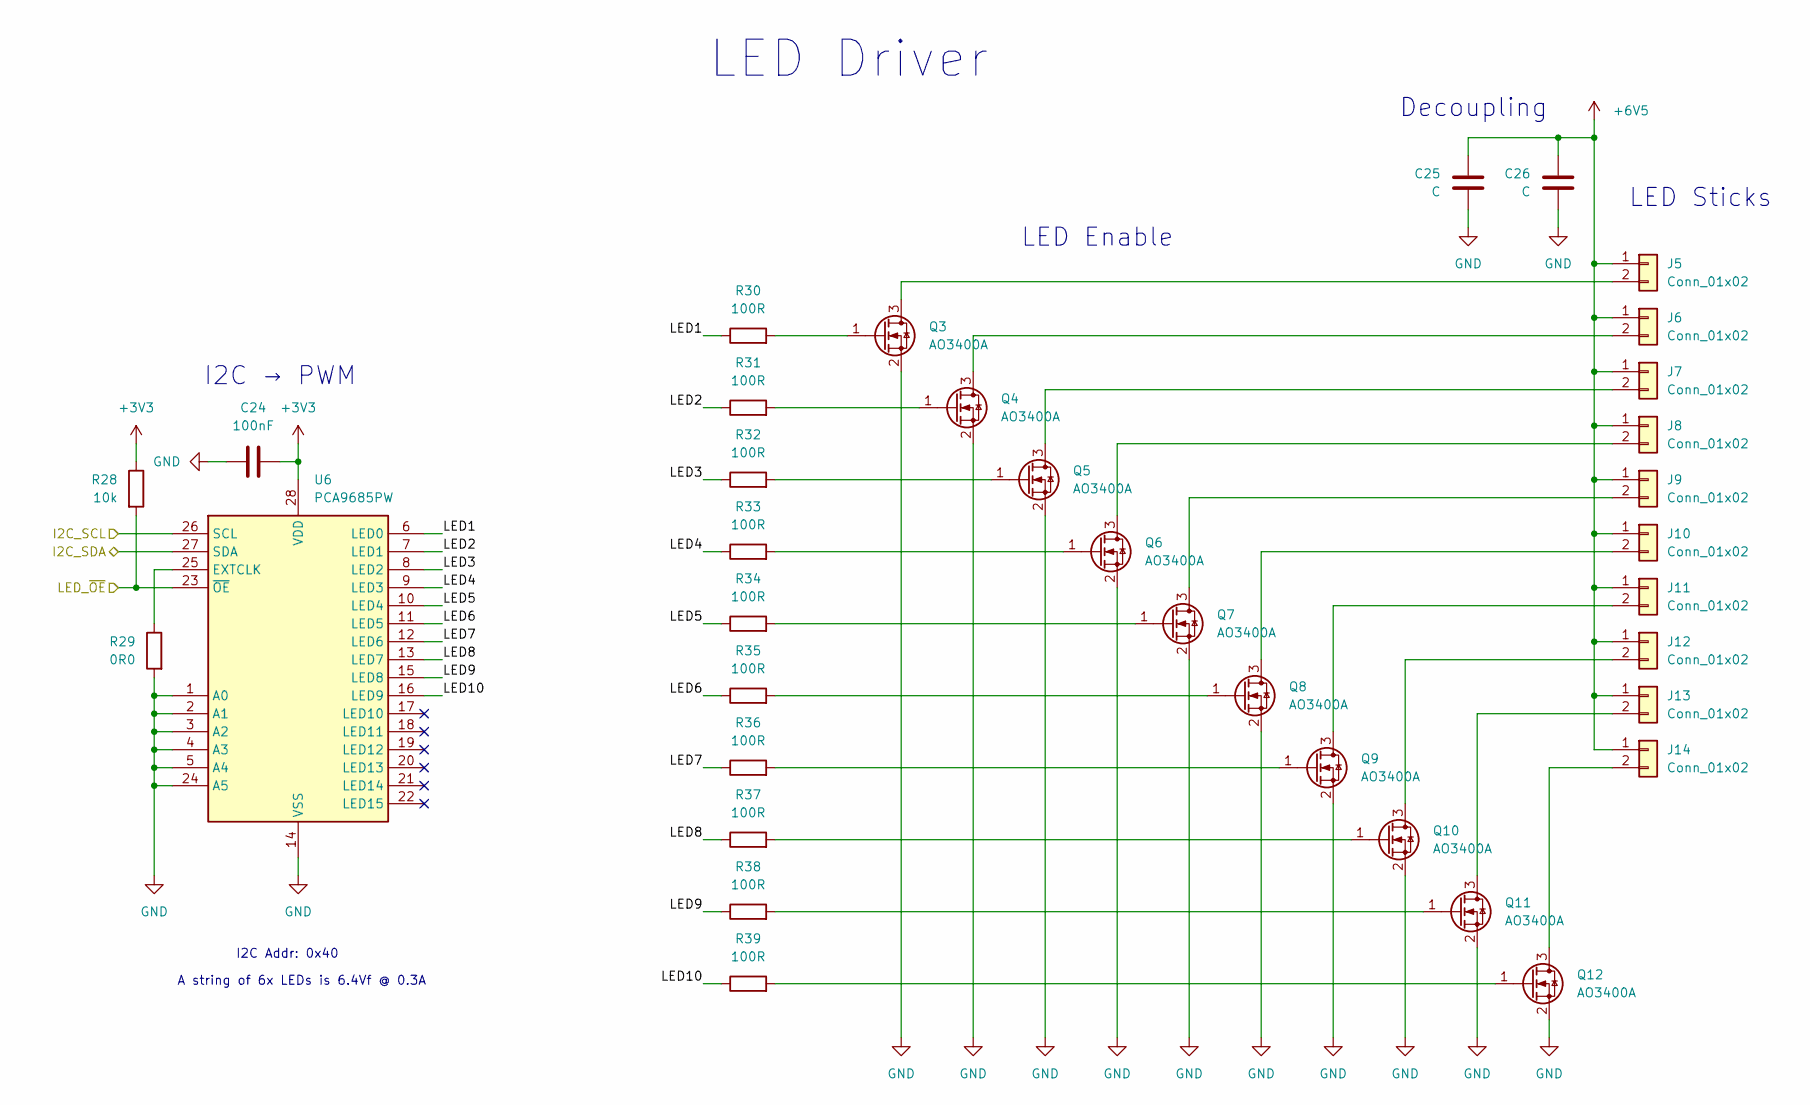
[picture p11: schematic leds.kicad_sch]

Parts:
C24: 100nF; C_0603_1608Metric
C25, C26: C
J5, J6, J7, J8, J9, J10, J11, J12, J13, J14: Conn_01x02; LED_Stick
Q3, Q4, Q5, Q6, Q7, Q8, Q9, Q10, Q11, Q12: AO3400A; SOT-23; LCSC C20917
R28: 10k; R_0603_1608Metric
R29: 0R0; R_0603_1608Metric
R30, R31, R32, R33, R34, R35, R36, R37, R38, R39: 100R; R_0603_1608Metric
U6: PCA9685PW; TSSOP-28_4.4x9.7mm_P0.65mm; LCSC C92206

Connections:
+3V3: C24.2, R28.1, U6.28 (VDD); also elsewhere on the board
+6V5: C25.1, C26.1, J5.1, J6.1, J7.1, J8.1, J9.1, J10.1, J11.1, J12.1, J13.1, J14.1; also elsewhere on the board
/CTRL/I2C_SCL: U6.26 (SCL); also elsewhere on the board
/CTRL/I2C_SDA: U6.27 (SDA); also elsewhere on the board
/CTRL/LED_~OE: R28.2, U6.23 (~OE); also elsewhere on the board
/LEDS/LED1: R30.1, U6.6 (LED0)
/LEDS/LED2: R31.1, U6.7 (LED1)
/LEDS/LED3: R32.1, U6.8 (LED2)
/LEDS/LED4: R33.1, U6.9 (LED3)
/LEDS/LED5: R34.1, U6.10 (LED4)
/LEDS/LED6: R35.1, U6.11 (LED5)
/LEDS/LED7: R36.1, U6.12 (LED6)
/LEDS/LED8: R37.1, U6.13 (LED7)
/LEDS/LED9: R38.1, U6.15 (LED8)
/LEDS/LED10: R39.1, U6.16 (LED9)
GND: C24.1, C25.2, C26.2, Q3.2 (S), Q4.2 (S), Q5.2 (S), Q6.2 (S), Q7.2 (S), Q8.2 (S), Q9.2 (S), Q10.2 (S), Q11.2 (S), Q12.2 (S), R29.2, U6.1 (A0), U6.2 (A1), U6.3 (A2), U6.4 (A3), U6.5 (A4), U6.14 (VSS), U6.24 (A5); also elsewhere on the board
unnamed: J5.2, Q3.3 (D)
unnamed: J6.2, Q4.3 (D)
unnamed: J7.2, Q5.3 (D)
unnamed: J8.2, Q6.3 (D)
unnamed: J9.2, Q7.3 (D)
unnamed: J10.2, Q8.3 (D)
unnamed: J11.2, Q9.3 (D)
unnamed: J12.2, Q10.3 (D)
unnamed: J13.2, Q11.3 (D)
unnamed: J14.2, Q12.3 (D)
unnamed: Q3.1 (G), R30.2
unnamed: Q4.1 (G), R31.2
unnamed: Q5.1 (G), R32.2
unnamed: Q6.1 (G), R33.2
unnamed: Q7.1 (G), R34.2
unnamed: Q8.1 (G), R35.2
unnamed: Q9.1 (G), R36.2
unnamed: Q10.1 (G), R37.2
unnamed: Q11.1 (G), R38.2
unnamed: Q12.1 (G), R39.2
unnamed: R29.1, U6.25 (EXTCLK)

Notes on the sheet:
I2C → PWM
A string of 6x LEDs is 6.4Vf @ 0.3A
I2C Addr: 0x40
LED Enable
LED Driver
LED Sticks
Decoupling

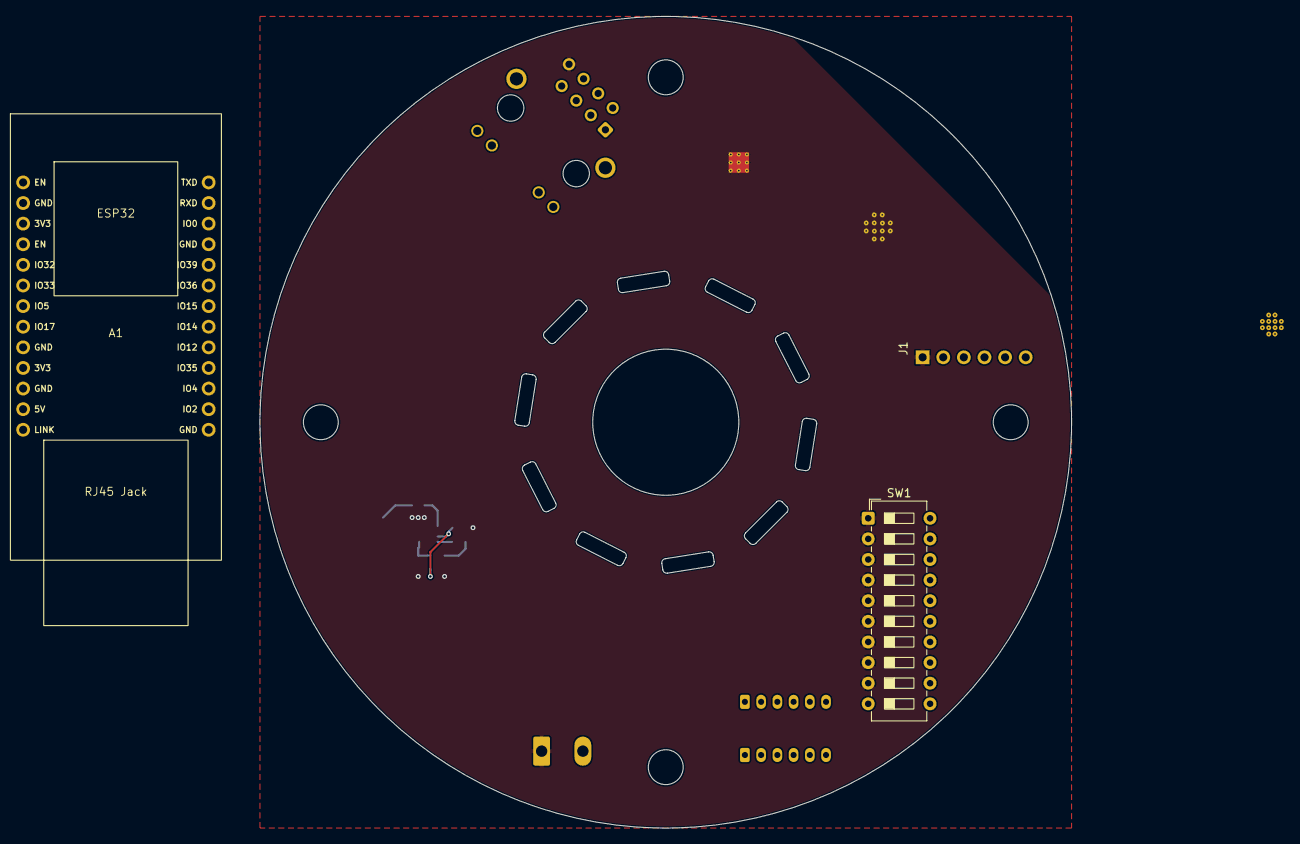
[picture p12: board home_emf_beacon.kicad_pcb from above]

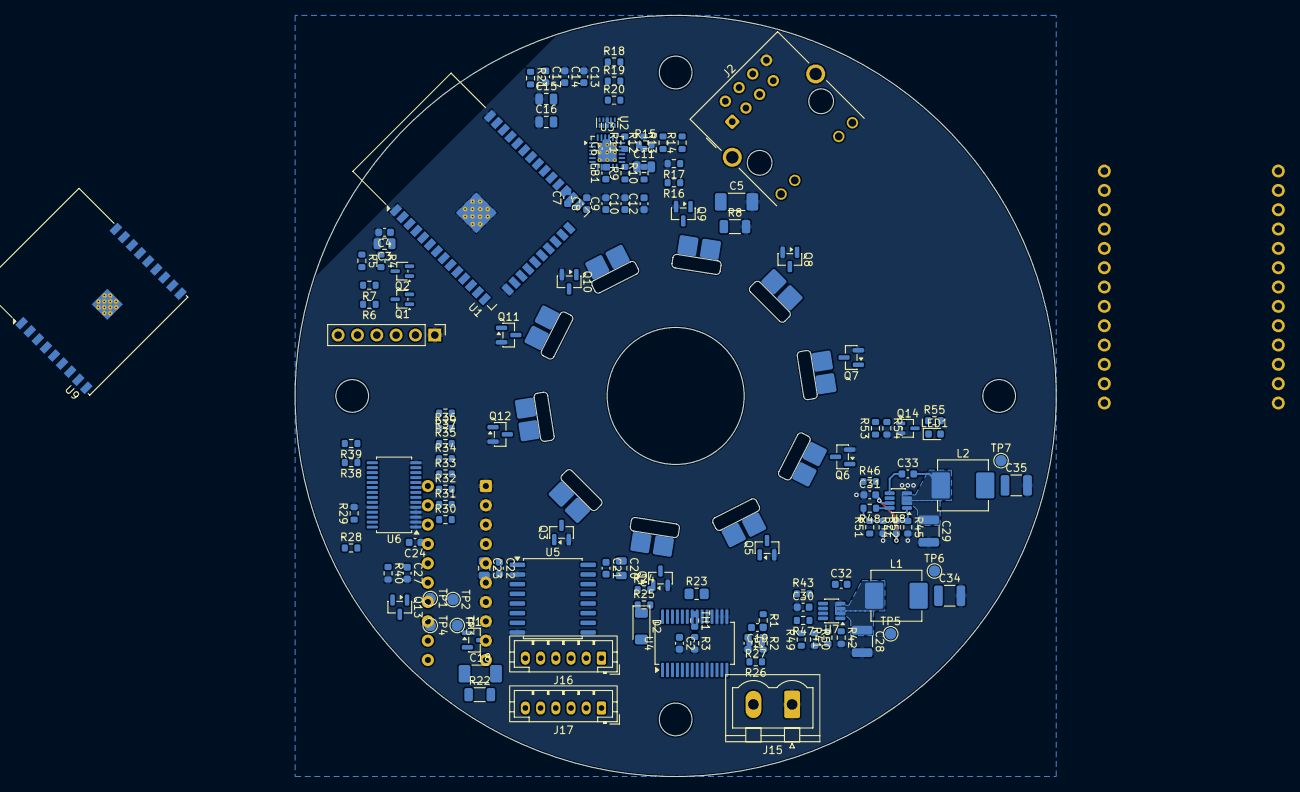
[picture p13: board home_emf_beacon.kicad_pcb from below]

Board: 2 copper layers, 100.0 x 100.0 mm, 146 parts (140 on the bottom side), 109 nets.

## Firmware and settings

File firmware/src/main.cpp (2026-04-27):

#include <Arduino.h>
#include <Wire.h>
#include <Adafruit_PWMServoDriver.h>
#include <Adafruit_MCP23X17.h>
#include <esp_dmx.h>
#include <WiFi.h>
#include <ESPAsyncWebServer.h>
#include <AsyncTCP.h>

// OTA

/** Settings **/
const uint32_t led_count = 10;
const uint32_t slot_count = led_count * 2; // 2 slots per LED
const uint32_t ctrl_loop = 5000; // control loop duration in ms
const uint32_t hold_last = 4000; // how long to keep last value in ms
const int32_t warning_temp = 500000; // temp to disable LEDs in millicelcius
const int wifi_channel = 1;

/** Pin Map **/
#define PIN_TEMP_MON  (0)
#define PIN_VCC_MON   (1)
#define PIN_SDA       (2)
#define PIN_SCL       (3)
#define PIN_I2C_INT   (4)
#define PIN_WIFI_EN   (5)
#define PIN_DMX_EN    (6)
#define PIN_LED_OE    (7)
#define PIN_LED       (8)
//#define PIN_DMX_RX   (20)
//#define PIN_DMX_TX   (21)
// ESP32-C3-DEVKITM-1 uses a USB↔Serial converter attached to IO20/21 not USB on IO18/19!
#define PIN_DMX_RX   (19)
#define PIN_DMX_TX   (18)

/** Hardware instantiations  **/
Adafruit_PWMServoDriver leds = Adafruit_PWMServoDriver(0x40);
Adafruit_MCP23X17 mcp;
hw_timer_t *led_timer = NULL;
dmx_port_t dmx_num = DMX_NUM_1;
AsyncWebServer server(80);
// OTA
uint32_t last_ctrl_update = 0x00;
uint32_t last_valid_dmx;
int32_t current_temp = 0x00, min_temp, max_temp;
uint32_t current_volts = 0x00, min_volts, max_volts;
uint32_t current_uptime = 0x00;
uint32_t dmx_address = 0x00;
uint8_t dmx_data[slot_count] = {0x00};
uint16_t led_brightness[led_count] = {0x00};
uint32_t led_half_period[led_count] = {0x00};
volatile uint32_t led_strobe_cnt[led_count] = {0x00};
volatile bool led_state[led_count] = {false};
volatile bool led_update_req[led_count] = {false};
bool wifi_ap_active = false;



// put function declarations here:
int32_t get_temp(void);
uint32_t get_volts(void);
uint16_t map_led_brightness(uint8_t);
uint32_t map_led_period(uint8_t);
void onTimer(void);
String processor(const String&);

char init_string[] = "\r\nLED Beacon\r\nCompiled on " __DATE__ " " __TIME__ "\r\n";

const char index_html[] PROGMEM = R"rawliteral(
<!DOCTYPE html>
<html>
<head>
  <meta name="viewport" content="width=device-width, initial-scale=1">
  <meta charset="UTF-8">
  <style>
    :root { --bg: #121212; --card: #1e1e1e; --text: #e0e0e0; --accent: #00e676; --dim: #888; }
    body { font-family: sans-serif; background: var(--bg); color: var(--text); margin: 0; padding: 20px; }
    header { text-align: center; margin-bottom: 30px; border-bottom: 1px solid #333; padding-bottom: 10px; }
    .grid { display: flex; flex-wrap: wrap; gap: 15px; max-width: 900px; margin: auto; }
    .card { background: var(--card); padding: 20px; border-radius: 16px; flex: 1 1 calc(50%% - 30px); min-width: 280px; border: 1px solid #2a2a2a; text-align: center; }
    .card h3 { margin: 0 0 12px 0; font-size: 0.85rem; text-transform: uppercase; color: var(--dim); display: flex; justify-content: center; align-items: center; gap: 8px; }
    .val { font-size: 2.2rem; font-weight: 700; color: var(--accent); margin-bottom: 8px; }
    .stats { font-size: 0.85rem; color: var(--dim); display: flex; justify-content: space-around; border-top: 1px solid #2a2a2a; padding-top: 10px; margin-top: 5px; }
    .system-list { text-align: left; display: inline-block; font-size: 0.85rem; line-height: 1.6; }
    .stat-label { color: #555; margin-right: 4px; }
  </style>
</head>
<body>
  <header><h1 style="margin:0; font-size: 1.5rem;">LED Beacon</h1></header>
  <div class="grid">
    <div class="card">
      <h3>📟 DMX Status</h3>
      <div class="val">%DMX_ADDR%</div>
      <div class="stats"><span><span class="stat-label">Last:</span>%LAST_DMX%</span></div>
    </div>
    <div class="card">
      <h3>⚡ Voltage</h3>
      <div class="val">%VOLT%</div>
      <div class="stats">
        <span><span class="stat-label">Min:</span>%VOLT_MIN%</span>
        <span><span class="stat-label">Max:</span>%VOLT_MAX%</span>
      </div>
    </div>
    <div class="card">
      <h3>🌡️ Temperature</h3>
      <div class="val">%TEMP%</div>
      <div class="stats">
        <span><span class="stat-label">Min:</span>%TEMP_MIN%</span>
        <span><span class="stat-label">Max:</span>%TEMP_MAX%</span>
      </div>
    </div>
    <div class="card">
      <h3>⚙️ System</h3>
      <div class="system-list">
        <div><span class="stat-label">Uptime:</span> %UPTIME%</div>
        <div><span class="stat-label">Build:</span> %BUILD%</div>
      </div>
    </div>
  </div>
</body>
</html>
)rawliteral";

void setup(void) {
  delay(2000);

  // init Serial
  Serial.begin(115200);
  Serial.write(init_string);

  // init GPIO
  pinMode(PIN_I2C_INT, INPUT);
  pinMode(PIN_LED_OE, OUTPUT);
  pinMode(PIN_DMX_EN, OUTPUT);
  pinMode(PIN_WIFI_EN, INPUT_PULLUP);
  pinMode(PIN_LED, OUTPUT);
  digitalWrite(PIN_LED_OE, HIGH);
  digitalWrite(PIN_DMX_EN, LOW);
  digitalWrite(PIN_LED, LOW);
  analogSetAttenuation(ADC_11db);
  Serial.println("GPIO initialised...");
 
  // init Timer
  led_timer = timerBegin(1, 80, true); // 80Mhz/80 = 1M ticks/sec for 1us resolution
  timerAttachInterrupt(led_timer, &onTimer, true);
  timerAlarmWrite(led_timer, 1000, true); // trigger every 1000us
  timerAlarmEnable(led_timer);
  Serial.println("Timer initialised...");

  // init I2C
  Wire.begin(PIN_SDA, PIN_SCL);
  //Wire.setClock(1000000);
  Wire.setClock(400000); // because of crap breadboard
  Serial.println("I²C initialised...");

  /*
  uint8_t error;
  Serial.println("\r\nScanning for I²C devices...");
  for (uint8_t address = 1; address < 127; address++) {
    Wire.beginTransmission(address);
    error = Wire.endTransmission();

    if (error == 0) {
      Serial.print("I²C device found at 0x");
      if (address < 0x10) Serial.print("0");
      Serial.println(address, HEX);
    } else if (error == 4) {
      Serial.print("Unknown error at 0x");
      if (address < 0x10) Serial.print("0");
      Serial.println(address, HEX);
    }
  }
  Serial.println("Finished scanning for I²C devices!\r\n");
  */

  // init MCP23017
  mcp.begin_I2C(0x20, &Wire);
  mcp.setupInterrupts(true, true, LOW);
  for(int i = 0; i < 16; i++) {
    mcp.pinMode(i, INPUT_PULLUP);
    if (i == 7 or i > 9) continue; // only configures 0→6 & 8→9
    mcp.setupInterruptPin(i, CHANGE);
  }
  Serial.println("MCP23017 initialised...");

  // init PCA9685
  leds.begin();
  leds.setPWMFreq(1000);
  leds.setOutputMode(true); // LEDs driven by external NMOS
  for (int i = 0; i < led_count; i++) leds.setPWM(i, 410*i, 0);
  digitalWrite(PIN_LED_OE, LOW); // enable LEDs!
  Serial.println("PCA9685 initialised...");

  // init DMX
  dmx_config_t config = DMX_CONFIG_DEFAULT;
  static dmx_personality_t personalities[] {
    {20, "10-Light Mode"} // 20 slots, custom name
  };
  int personality_count = 1;
  dmx_driver_install(dmx_num, &config, personalities, personality_count);
  dmx_set_pin(dmx_num, PIN_DMX_TX, PIN_DMX_RX, PIN_DMX_EN);
  Serial.println("DMX initialised...");
  
  // init Watchdog
  
  // init WiFi
  WiFi.softAP("LED_Beacon_Status", "password123", wifi_channel);
  IPAddress IP = WiFi.softAPIP();
  Serial.print("AP IP Address: ");
  Serial.println(IP);
  server.on("/", HTTP_GET, [](AsyncWebServerRequest *request){
    Serial.println("Request received!");
    // The 'processor' argument tells the server to swap out the %VARIABLES%
    request->send(200, "text/html", index_html, processor);
  });
  server.begin();

  // init OTA

  // set starting min & max
  current_temp = get_temp();
  min_temp = current_temp;
  max_temp = current_temp;
  current_volts = get_volts();
  min_volts = current_volts;
  max_volts = current_volts;

  Serial.println("Setup complete!\r\nStarting loop...");
}

void loop(void) {
  
  // Get DMX packet and update LEDs
  dmx_packet_t packet;
  if (dmx_receive(dmx_num, &packet, 0)) {
    if (!packet.err) {
      dmx_read_offset(dmx_num, dmx_address, dmx_data, slot_count);
      last_valid_dmx = millis();
      //dmxSignalLost = false;

      uint16_t new_brightness;
      uint32_t new_half_period;
      for (int i = 0; i < led_count; i++) {
        new_brightness = map_led_brightness(dmx_data[i]);
        if (led_brightness[i] != new_brightness) {
          led_brightness[i] = new_brightness;
          led_update_req[i] = true;
        }

        new_half_period = map_led_period(dmx_data[i + led_count]);
        if (led_half_period[i] != new_half_period) {
          led_half_period[i] = new_half_period;
          if (new_half_period == 0) {
            // force an update if LED is to be fully on
            led_update_req[i] = true;
          }
        }          
      }
    }
  }

  // handle DMX timeout
  if (millis() - last_valid_dmx > hold_last) {
    for (int i = 0; i < led_count; i++) {
      if (led_brightness[i] != 0x00) {
        led_brightness[i] = 0x00;
        led_half_period[i] = 0x00;
        led_update_req[i] = true;
        led_state[i] = true;
      }
    }
  }

  // update LEDs
  for (int i = 0; i < led_count; i++) {
    if (led_update_req[i]) {
      led_update_req[i] = false;

      uint16_t on_time = 410 * i;
      uint16_t off_time;
      
      if (led_state[i] && led_brightness[i] > 0x00) {
        if(led_brightness[i] == 4095) {
          // special PCA9685 'always on' mode
          on_time = 4096;
          off_time = 0;
        } else {
          off_time = (on_time + led_brightness[i]) % 4096;
        }
      } else {
        // 'always off' mode
        off_time = on_time;
      }
     
      leds.setPWM(i, on_time, off_time);
    }
  }
  
  if (millis() - last_ctrl_update >= ctrl_loop) {
    last_ctrl_update = millis();

    //enable/disable WiFi AP
    
    bool wifi_enable = ~digitalRead(PIN_WIFI_EN);
    /*
    if (wifi_enable && !wifi_ap_active) {
      WiFi.softAP("LED_Beacon_Ctrl", "password123");
      server.begin();
      apActive = true;
    } 
    else if (!wifi_enable && wifi_ap_active) {
      server.end();
      WiFi.softAPdisconnect(true);
      WiFi.mode(WIFI_OFF);
      apActive = false;
    }
    */

    // get current VCC in and temperature
    current_volts = get_volts();
    current_temp = get_temp();

    // update min/max temp/volts    
    if (current_temp > -50000 && current_temp < 150000) {
      // but only if temp is between -50°C and 150°C
      min_temp = min(min_temp, current_temp);
      max_temp = max(max_temp, current_temp);
    }
    min_volts = min(min_volts, current_volts);
    max_volts = max(max_volts, current_volts);

    // dealing with excessive temp
    if (current_temp >= warning_temp) {
      digitalWrite(PIN_LED_OE, HIGH); // disable LEDs while too hot!
    } else if (current_temp <= (warning_temp - 5000)) {
      digitalWrite(PIN_LED_OE, LOW); // enable LEDs now it's cooler!
    }
    
    // not sure what actions to take on:      
      // under voltage
      // over voltage
    
    current_uptime = esp_timer_get_time() / 1000000;
       
    // check DMX address
    if (digitalRead(PIN_I2C_INT) == LOW) {
      uint16_t dmx_adr_switches = ~mcp.readGPIOAB(); // read and flip switch states from ACTIVE_LOW to ACTIVE_HIGH
      dmx_adr_switches = (dmx_adr_switches & 0x7F) | ((dmx_adr_switches & 0x0300) >> 1);  // keep 0→6 & 8→9 and concatenate to remove 7
      dmx_address = dmx_adr_switches + 1; // offset and save DMX address
    }

    // update USB status
      
  }

}

void IRAM_ATTR onTimer(void) {
  for (int i = 0; i < 10; i++) {
    
    if (led_half_period[i] == 0) {
      if (!led_state[i]) { 
        led_state[i] = true;
        led_update_req[i] = true;
      }
      led_strobe_cnt[i] = 0; // Keep counter reset
      continue;
    }

    led_strobe_cnt[i]++;
    if (led_strobe_cnt[i] >= led_half_period[i]) {
      led_strobe_cnt[i] = 0;
      led_state[i] = !led_state[i];
      led_update_req[i] = true;
    }
  }
}

/** 8bit to 12bit gamma look up table
 * uint16_t = (uint8_t / (2^8 - 1)) ^ 2.8 * (2^12 - 1)
 */
static const uint16_t gamma12_table[] PROGMEM = {
    0, 0, 0, 0, 0, 0, 0, 0, 0, 0, 0, 1, 1, 1, 1, 1,
    2, 2, 2, 3, 3, 4, 4, 5, 5, 6, 7, 8, 8, 9, 10, 11,
    12, 13, 15, 16, 17, 18, 20, 21, 23, 25, 26, 28, 30, 32, 34, 36,
    38, 40, 43, 45, 48, 50, 53, 56, 59, 62, 65, 68, 71, 75, 78, 82,
    85, 89, 93, 97, 101, 105, 110, 114, 119, 123, 128, 133, 138, 143, 149, 154,
    159, 165, 171, 177, 183, 189, 195, 202, 208, 215, 222, 229, 236, 243, 250, 258,
    266, 273, 281, 290, 298, 306, 315, 324, 332, 341, 351, 360, 369, 379, 389, 399,
    409, 419, 430, 440, 451, 462, 473, 485, 496, 508, 520, 532, 544, 556, 569, 582,
    594, 608, 621, 634, 648, 662, 676, 690, 704, 719, 734, 749, 764, 779, 795, 811,
    827, 843, 859, 876, 893, 910, 927, 944, 962, 980, 998, 1016, 1034, 1053, 1072, 1091,
    1110, 1130, 1150, 1170, 1190, 1210, 1231, 1252, 1273, 1294, 1316, 1338, 1360, 1382, 1404, 1427,
    1450, 1473, 1497, 1520, 1544, 1568, 1593, 1617, 1642, 1667, 1693, 1718, 1744, 1770, 1797, 1823,
    1850, 1877, 1905, 1932, 1960, 1988, 2017, 2045, 2074, 2103, 2133, 2162, 2192, 2223, 2253, 2284,
    2315, 2346, 2378, 2410, 2442, 2474, 2507, 2540, 2573, 2606, 2640, 2674, 2708, 2743, 2778, 2813,
    2849, 2884, 2920, 2957, 2993, 3030, 3067, 3105, 3143, 3181, 3219, 3258, 3297, 3336, 3376, 3416,
    3456, 3496, 3537, 3578, 3619, 3661, 3703, 3745, 3788, 3831, 3874, 3918, 3962, 4006, 4050, 4095
};

uint16_t map_led_brightness(uint8_t brightness) {
  
  return gamma12_table[brightness];
}

// This table stores the ms delay between TOGGLES (Half-Period)
static const uint32_t strobe_half_period_table[] PROGMEM = {
    0, 2500, 2415, 2336, 2261, 2191, 2126, 2064, 2006, 1951, 1899, 1850, 1803, 1759, 1716, 1676,
    1637, 1600, 1565, 1531, 1499, 1468, 1438, 1409, 1382, 1355, 1329, 1305, 1281, 1258, 1236, 1214,
    1194, 1174, 1154, 1136, 1118, 1100, 1083, 1067, 1051, 1035, 1020, 1006, 992, 978, 965, 952,
    939, 927, 915, 903, 892, 881, 870, 860, 850, 840, 830, 821, 811, 802, 793, 785,
    776, 768, 760, 752, 745, 737, 730, 723, 716, 709, 702, 696, 689, 683, 677, 671,
    665, 659, 653, 647, 642, 636, 631, 626, 621, 616, 611, 606, 601, 597, 592, 588,
    583, 579, 575, 571, 566, 562, 558, 554, 550, 547, 543, 539, 536, 532, 529, 525,
    522, 518, 515, 512, 508, 505, 502, 499, 496, 493, 490, 487, 484, 481, 478, 475,
    472, 470, 467, 464, 462, 459, 456, 454, 451, 449, 446, 444, 441, 439, 437, 434,
    432, 430, 427, 425, 423, 421, 418, 416, 414, 412, 410, 408, 406, 404, 402, 400,
    398, 396, 394, 392, 390, 388, 386, 384, 383, 381, 379, 377, 376, 374, 372, 371,
    369, 367, 366, 364, 362, 361, 359, 358, 356, 355, 353, 352, 350, 349, 348, 346,
    345, 343, 342, 341, 339, 338, 337, 335, 334, 333, 331, 330, 329, 328, 326, 325,
    324, 323, 322, 321, 319, 318, 317, 316, 315, 314, 313, 312, 311, 310, 309, 308,
    306, 305, 304, 303, 302, 301, 300, 299, 298, 297, 296, 295, 294, 293, 292, 291,
    290, 289, 288, 287, 286, 285, 284, 283, 282, 281, 281, 280, 279, 278, 277, 16
};

uint32_t map_led_period(uint8_t period) {

  // FILL ME OUT!
  // freq: 1-30Hz, 0.289-16.667Hz
  // msg: 0 = solid, 1 = slow, 255 = fast
  // DMX 1   = 5.000 seconds
  // DMX 255 = 0.033 seconds
  
  return strobe_half_period_table[period];
}

String processor(const String& var) {
  if(var == "DMX_ADDR") return String(dmx_address);
  if(var == "LAST_DMX") return String((millis() - last_valid_dmx)/1000) + "s ago";
  if(var == "VOLT")     return String(((float)current_volts/1000), 2) + "V";
  if(var == "VOLT_MIN") return String(((float)min_volts/1000), 2) + "V";
  if(var == "VOLT_MAX") return String(((float)max_volts/1000), 2) + "V";
  if(var == "TEMP")     return String(((float)current_temp/1000), 2) + "&deg;C";
  if(var == "TEMP_MIN") return String(((float)min_temp/1000), 2) + "&deg;C";
  if(var == "TEMP_MAX") return String(((float)max_temp/1000), 2) + "&deg;C";
  if(var == "BUILD")    return String(__DATE__) + " " + String(__TIME__);
  if(var == "UPTIME") {
    uint32_t t = current_uptime;
    uint32_t s = t % 60;
    uint32_t m = (t / 60) % 60;
    uint32_t h = (t / 3600) % 24;
    uint32_t d = t / 86400;
  
    String res = "";
    if (d > 0) res += String(d) + "d ";
    if (h > 0 || d > 0) res += String(h) + "h ";
    if (m > 0 || h > 0 || d > 0) res += String(m) + "m ";
    res += String(s) + "s";
    return res;
  }
  return String();
}

/** 
 * Lookup table for NCP15XH103F03RC 
 * Based on 10k pull-down (to GND) and 12-bit ADC (0-4095)
 * Format: {ADC_Value, Temp_in_C}
 */
struct TempPoint {
    int16_t adc;
    int16_t temp;
};

// LUT for: 3.3V -> 10k Resistor -> IO0 -> Thermistor + 1uF -> GND
const TempPoint lut[] = {
    {3115, -10}, {2703, 0},  {2263, 10}, {1850, 20}, 
    {1485, 30},  {1176, 40}, {924, 50},  {724, 60}, 
    {568, 70},   {449, 80},  {356, 90},  {286, 100}
};
const size_t LUT_SIZE = sizeof(lut) / sizeof(lut[0]);

int32_t get_temp(void) {

  int32_t raw_temp = 0x00;

  for (int i = 0; i < 8; i++) {
    raw_temp += analogRead(PIN_TEMP_MON);
    delay(1);
  }
  raw_temp /= 8;

  // Failsafe: Thermistor shorted to 3.3V (Vout low)
  if (raw_temp  < 50) return 300000; 
  // Failsafe: Thermistor open/disconnected (Vout high)
  if (raw_temp > 4050) return -300000;

  // Linear Interpolation
  for (size_t i = 0; i < LUT_SIZE - 1; i++) {
    if (raw_temp <= lut[i+1].adc) {
      int32_t x0 = lut[i].adc;
      int32_t x1 = lut[i+1].adc;
      int32_t y0 = lut[i].temp * 1000; // Convert to millidegrees
      int32_t y1 = lut[i+1].temp * 1000;

      // millidegrees = y0 + (raw_temp - x0) * (y1 - y0) / (x1 - x0)
      return y0 + (raw_temp - x0) * (y1 - y0) / (x1 - x0);
    }
  }

  return 300000; // Out of range high
}

uint32_t get_volts(void) {
  const uint32_t lsb_2_uvolts = 5802; // Vadc × ((62kΩ + 10kΩ) ÷ 10kΩ) = VCC
  uint32_t raw_volts = 0x00;

  for (int i = 0; i < 8; i++) {
    raw_volts += analogRead(PIN_VCC_MON);
    delay(1);
  }
  raw_volts /= 8;

  // convert to millivolts
  raw_volts = ((raw_volts * lsb_2_uvolts) + 500) / 1000; // outputs millivolts

  return raw_volts;
}

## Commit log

2026-04-20 adjusting folders
    [art-net.kicad_sch, ctrl.kicad_sch, dmx512.kicad_sch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]
2026-04-20 removing old board files
    [art-net.kicad_sch, ctrl.kicad_sch, dmx512.kicad_sch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]
2026-04-21 docs: auto-generate schematic PDF
2026-04-21 fixing issues, adding parts
    [art-net.kicad_sch, ctrl.kicad_sch, dmx512.kicad_sch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]
2026-04-27 Update main.cpp
    Fixing strobe data offset.
    [main.cpp]
2026-04-27 fixed timer
